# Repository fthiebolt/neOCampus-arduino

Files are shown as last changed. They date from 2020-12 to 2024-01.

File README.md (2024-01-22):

# neOCampus-arduino | home of the neOSensor end-devices #
________________________________________________________________
# WE MOVED #
# to https://gitlab.irit.fr/gis-neocampus/neosensor/neOCampus-arduino #
________________________________________________________________

This repository provides support for the following neOCampus boards:
  * neOSensor boards based on ESP32
  * neOSensor-AirQuality board (ESP32) from CNRS' LCC lab.
  * neOSensor boards based on ESP8266 (rev. >= V2)

All this work was undertaken at Université Toulouse 3 / IRIT laboratory in the context of the [neOCampus](https://neocampus.org "neOCampus corporate") operation.

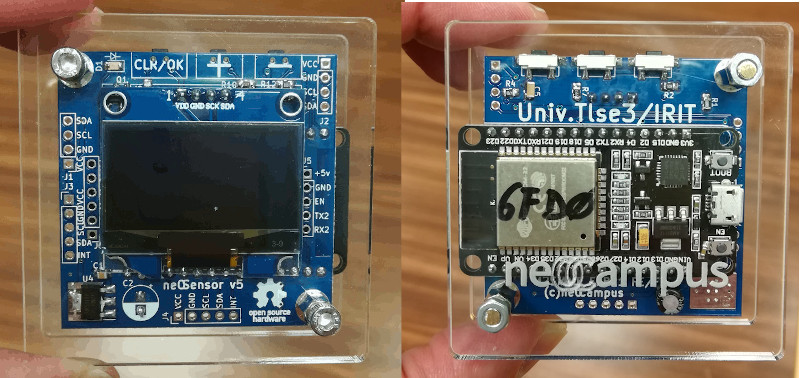
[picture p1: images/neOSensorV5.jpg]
neOSensorv5


## neOSensor boards ##
neOSensor first boards releases were based on esp8266. Nowadays, we added support for esp32 and CubeCell devices :)

We added support to our neOCampus IoT management infrastructure named [sensOCampus](https://neocampus.univ-tlse3.fr "neOCampus's Wiki Home") to enable a central configuration for all of our neOSensor boards; these boards will then be able to publish their data to our infrastructure and to have those data stored in our databases.

### neOSensor-AirQuality board ###
This board comes from CNRS LCC lab, it's a PhD work undertaken by Aymen Sendi (aymen.sendi@laas.fr).
The board features four specific sensors able to measure NO2, CO, CH20, NO2 alternate.

## Getting started ##
First of all, you ought to install esp32, esp8266 or CubeCell support in your Arduino IDE (IDE version <2).

| Device | Release | Arduino Board Manager json file |
|---|---|---|
| esp8266  | 3.1.2 | https://arduino.esp8266.com/stable/package_esp8266com_index.json |
| esp32 | 2.0.11 | https://raw.githubusercontent.com/espressif/arduino-esp32/gh-pages/package_esp32_index.json |
| CubeCell | *latest*  | https://github.com/HelTecAutomation/CubeCell-Arduino/releases/download/V1.3.0/package_CubeCell_index.json  |
| stm32 | *latest*  | https://github.com/stm32duino/BoardManagerFiles/raw/main/package_stmicroelectronics_index.json |

Then, run script `./deploy.sh` and boards will get added to your Arduino boards list :)

If not already installed, you'll need python-serial package; thus either you install it at the system level
```
[fedora] dnf -y install python3-pyserial
[ubuntu] apt-get -y install python3-serial python-is-python3
```

Once you've launched the Arduino IDE, before compiling and uploading sketches to your board, you need to undertake the following steps:
  - @preferences --> set your Arduino sketchbook to `~/neOCampus-arduino/neosensor' ... this will lead to proper libraries
  - either select boards 'ESP32 arduino' --> 'neOSensor' or 'neOSensor-AirQuality' or select board 'ESP8266 arduino' --> 'neOSensor'
  - compile and upload :)
  - debug serial link speed 115200

### WiFi setup ###
Only for ESP based boards.

Once started, the board will provides a WiFi Access Point (AP) named: `neOSensor_xxxx` where xxxx are the MAC address last bytes.

**First time setup**\
In this case, AP will get available for 5mn for you to configure SSID along with WPA2 key.
So you'll have to search with your smartphone for this peucliar AP, and then connect. In case automatic redirection does not work, open a browser with http:192.168.4.1

**Changing WiFi setup**\
Once WiFi has been set, on each reboot, the neOSensor AP will get available for 50s in order for you to tweak some parameters ... or to change the WiFi it connects to.

**Reset whole configuration**\
To erase all of the previously set parameters (including WiFi settings), press the RST button for 10s when powering the device.

***

## Create branch | development of a new feature ##
In order to work on a new feature, best is to create a new branch that will get merged later during a *pull request*

```
git switch -C feature-xxxxx
```

For first commit:
```
git push --set-upstream origin feature-xxxxx
```

... then `./git-push.sh` on subsequent commits

## Merge branch | integration of an existing feature ##
After having successfully completed yout feature, you need to create a *pull request* to get your code integrated into the main branch:

```
git branch
git checkout master
git merge feature-xxxxx
./git-push.sh
```
https://www.w3schools.com/git/git_branch_merge.asp?remote=github

In the end, you can delete your local branch: `git branch -d feature-xxxxx`

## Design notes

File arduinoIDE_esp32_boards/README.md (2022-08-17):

===== [aug.22] extending lwip with NTP servers from DHCP answer ======

WARNING: only esp32 target will benefits from this enhancement (we don't have compiled for
others targets like esp32s2, s3, c3 ...)

cp opt.h ~/.arduino15/packages/esp32/hardware/esp32/2.0.4/tools/sdk/esp32/include/lwip/lwip/src/include/lwip/
cp *.a ~/.arduino15/packages/esp32/hardware/esp32/2.0.4/tools/sdk/esp32/lib/

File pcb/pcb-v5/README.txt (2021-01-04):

This directory holds the following:

- pcbv5.pro         --> main neOSensor board (esp32 30 pins based version)
    [dec.20] pre-release in lora repository @ bitbucket
- panelization files (4 designs in a single 100x100mm board)

To launch Kicad: #> kicad xxx.pro

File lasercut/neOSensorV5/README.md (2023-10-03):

# neOSensor V5 | PMMA enclosure #
_________________________________

** .wcvr files ** are from the CampusFab's laser cutter

DXF files have been edited through the 'LibreCAD' tool

## FILES ##
  - 

TO BE CONTINUED
 24K -rw-r--r-- 1 francois cloud  24K Oct  7  2021 first-run.plt
984K -rw-r--r-- 1 francois cloud 983K Dec 13  2021 first-run.wcvr
1,6M -rw-r--r-- 1 francois cloud 1,6M Dec 13  2021 large-plate.wcvr
 28K -rw-r--r-- 1 francois cloud  28K Dec 13  2021 neOSensor-sds011_flat.dxf
120K -rw-r--r-- 1 francois cloud 118K Dec 13  2021 neOSensor-sds011_flat.wcvr
 20K -rw-r--r-- 1 francois cloud  19K Jun 18  2021 neOSensor_IR.dxf
 20K -rw-r--r-- 1 francois cloud  20K Sep 28  2021 neOSensor_V2.1_back.dxf
 20K -rw-r--r-- 1 francois cloud  19K Sep 28  2021 neOSensor_V2.2_back.dxf
 48K -rw-r--r-- 1 francois cloud  45K Dec  9  2021 neOSensor_bureau.dxf
 32K -rw-r--r-- 1 francois cloud  32K Dec  7  2021 neOSensor_bureauV2_Bottom5mm.dxf
 40K -rw-r--r-- 1 francois cloud  38K Dec  7  2021 neOSensor_bureauV2_Top3mm.dxf
100K -rw-r--r-- 1 francois cloud  98K Dec 13  2021 neOSensor_bureau-run1.wcvr
 88K -rw-r--r-- 1 francois cloud  87K Apr  9  2021 neOSensor_logo.dxf
 20K -rw-r--r-- 1 francois cloud  18K Apr  9  2021 neOSensor_plain.dxf
1,5M -rw-r--r-- 1 francois cloud 1,5M Dec 13  2021 second-run.wcvr

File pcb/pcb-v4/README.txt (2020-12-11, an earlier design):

This directory holds several Kicad5 pcbs:

- pcbv4.pro         --> main neOSensor board (esp8266 version)
- pcbv4-temp.pro    --> addon board featuring a temperature sensor
- neOSensorV4_panel --> neOSensors panelized ;)

Note: we get inspiration from Arduino MKR1300 schematic for power supply

To launch Kicad: #> kicad xxx.pro

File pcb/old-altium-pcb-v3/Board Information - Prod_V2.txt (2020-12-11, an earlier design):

Board Information Report
Filename     : H:\Mes documents\DEV\ALTIUM\Altium conceptions\Son_BU\Prod_V2.PcbDoc
Date         : 04/04/2017
Time         : 14:27:02
Time Elapsed : 00:00:00

General
    Board Size, 152.4mmx101.6mm
    Components on board, 0
count : 2

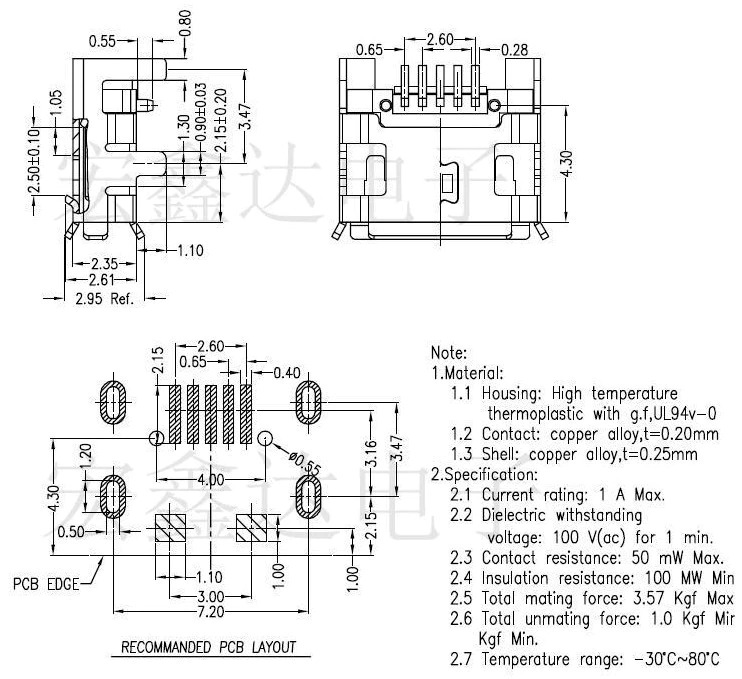
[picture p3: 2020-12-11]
pcb/doc/micro-usb-aliexpress-detail2.jpg

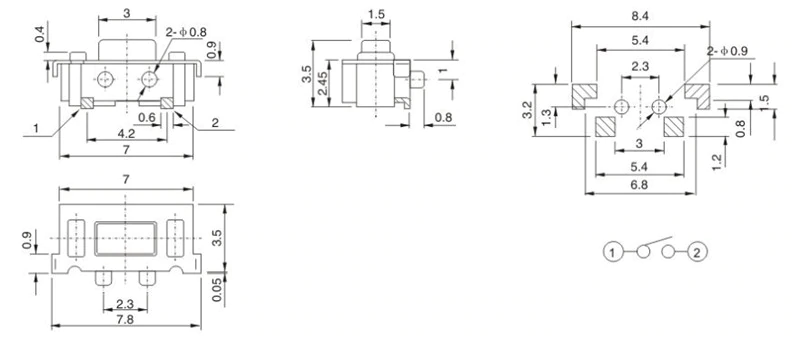
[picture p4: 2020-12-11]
pcb/doc/G71Y_horizontal_button.png

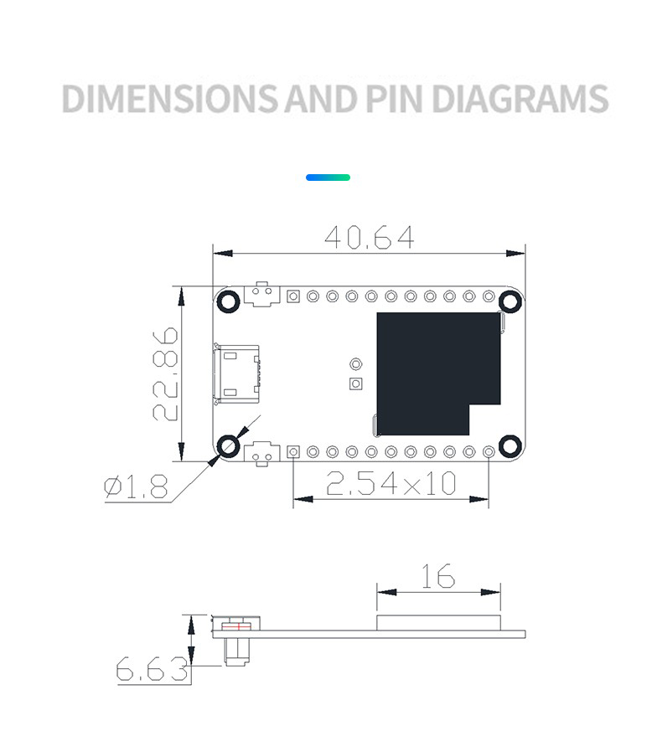
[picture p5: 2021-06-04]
pcb/doc/HTCC-AB01-mechnical.jpg

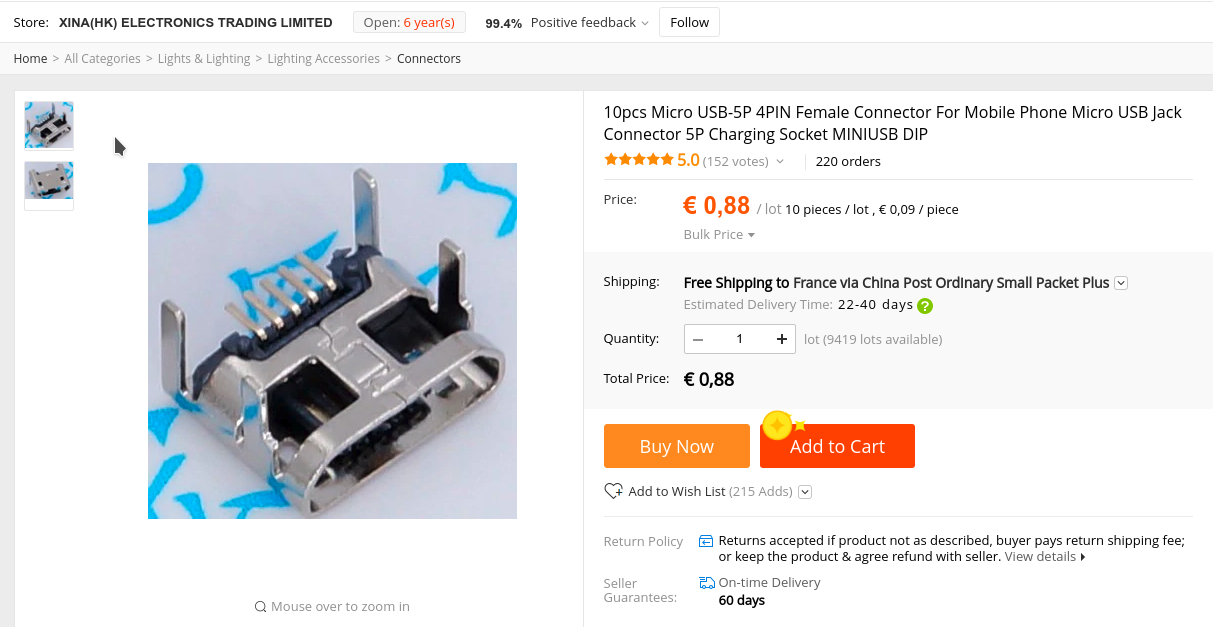
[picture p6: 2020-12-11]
pcb/doc/micro-usb-aliexpress.png

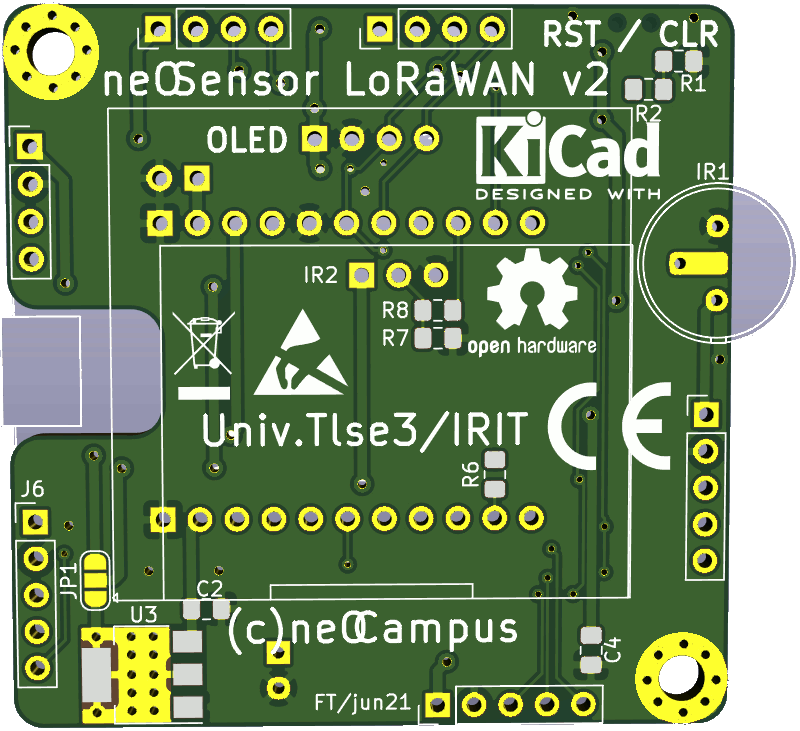
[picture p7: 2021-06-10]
pcb/lorawan-v2/neOsensor-LoRaWANV2.png

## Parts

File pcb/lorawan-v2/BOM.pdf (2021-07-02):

neOsensor-LoRaWANV2

Page 1

Reference(s) | Value | LibPart | Footprint
C1 | 1uF | Device:C_Small | Capacitor_SMD:C_0805_2012Metric_Pad1.15x1.40mm_HandSolder
C2 | 100n | Device:C_Small | Capacitor_SMD:C_0805_2012Metric_Pad1.15x1.40mm_HandSolder
C3 | 100ÂµF 6.3v | Device:CP1_Small | Capacitor_THT:CP_Radial_D5.0mm_P2.50mm
C4 | 100n | Device:C_Small | Capacitor_SMD:C_0805_2012Metric_Pad1.18x1.45mm_HandSolder
H1, H2 | 3.2mm for MH3 screw | Mechanical:MountingHole_Pad | MountingHole:MountingHole_3.2mm_M3_Pad
IR1 | IRsensor | neosensor_addon:IRsensor | neosensor_addon:IRsensor_TH_and_smd
IR2 | HC-SR01 | neosensor_addon:HC-SR01 | neosensor_addon:PIR_HC-SR01
J1, J3, J5, J6, J7 | Conn_01x05 | Connector_Generic:Conn_01x05 | Connector_PinHeader_2.54mm:PinHeader_1x05_P2.54mm_Vertical
J2 | Conn_01x02 | Connector_Generic:Conn_01x02 | Connector_JST:JST_PH_S2B-PH-K_1x02_P2.00mm_Horizontal
J4 | Conn_01x04 | Connector_Generic:Conn_01x04 | Connector_PinHeader_2.54mm:PinHeader_1x04_P2.54mm_Vertical
JP1 | SolderJumper_3_Open | Jumper:SolderJumper_3_Open | Jumper:SolderJumper-3_P1.3mm_Open_RoundedPad1.0x1.5mm
R1, R2, R6 | 15k | Device:R_Small | Resistor_SMD:R_0805_2012Metric_Pad1.15x1.40mm_HandSolder
R3, R4 | 4K7 | Device:R_Small | Resistor_SMD:R_0805_2012Metric_Pad1.15x1.40mm_HandSolder
R5, R8 | 470 Device:R_Small | | Resistor_SMD:R_0805_2012Metric_Pad1.15x1.40mm_HandSolder
R7 | 47K | Device:R_Small | Resistor_SMD:R_0805_2012Metric_Pad1.15x1.40mm_HandSolder
SW1 | G71Y | neosensor_addon:G71Y | neosensor_addon:G71Y_Âµsw_smd
U1 | OLED1.3_I2C | neosensor_addon:OLED1.3_I2C | neosensor_addon:OLED1.3_I2C
U2 | ATECC508A | neosensor_addon:ATECC508A | neosensor_addon:SOIC-8_3.9x5.4mm_P1.27mm_HandSolder
U3 | AMS1117-3.3 | Regulator_Linear:AMS1117-3.3 | Package_TO_SOT_SMD:SOT-223-3_TabPin2
U4 | HTCC-AB01 | neosensor_addon:HTCC-AB01 | neosensor_addon:HTCC-AB01

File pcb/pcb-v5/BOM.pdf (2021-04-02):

neOSensorV5.1

Page 1

Reference(s) | Value | LibPart | Footprint
C1, C3 | 100nF | Device:C_Small | Resistor_SMD:R_0805_2012Metric_Pad1.20x1.40mm_HandSolder
C2 | 100µF 6.3v | Device:CP1_Small | Capacitor_THT:CP_Radial_D5.0mm_P2.50mm
C4, C5 | 1uF | Device:C_Small | Resistor_SMD:R_0805_2012Metric_Pad1.20x1.40mm_HandSolder
D1 | Red | Device:LED_Small_ALT | LED_SMD:LED_0805_2012Metric_Pad1.15x1.40mm_HandSolder
H1, H2 | 3.2mm for MH3 screw | Mechanical:MountingHole_Pad | MountingHole:MountingHole_3.2mm_M3_Pad
J1, J2 | Conn_01x04 | Connector_Generic:Conn_01x04 | Connector_PinHeader_2.54mm:PinHeader_1x04_P2.54mm_Vertical
J3, J4, J5 | Conn_01x05 | Connector_Generic:Conn_01x05 | Connector_PinHeader_2.54mm:PinHeader_1x05_P2.54mm_Vertical
J6 | Conn_01x06 | Connector_Generic:Conn_01x06 | Connector_PinHeader_2.54mm:PinHeader_1x06_P2.54mm_Vertical
Q1 | 2N7002 | Transistor_FET:2N7002 | Package_TO_SOT_SMD:SOT-23_Handsoldering
R1 | 150 Device:R_Small | | Resistor_SMD:R_0805_2012Metric_Pad1.20x1.40mm_HandSolder
R2, R7, R9, R10, R11, R12, R21 | 15k | Device:R_Small | Resistor_SMD:R_0805_2012Metric_Pad1.20x1.40mm_HandSolder
R3, R5 | 470 Device:R_Small | | Resistor_SMD:R_0805_2012Metric_Pad1.20x1.40mm_HandSolder
R4, R8 | 4K7 | Device:R_Small | Resistor_SMD:R_0805_2012Metric_Pad1.20x1.40mm_HandSolder
R13, R14, R15, R18 | 22k | Device:R_Small | Resistor_SMD:R_0805_2012Metric_Pad1.20x1.40mm_HandSolder
R16, R17, R19, R20 | 33k | Device:R_Small | Resistor_SMD:R_0805_2012Metric_Pad1.20x1.40mm_HandSolder
SW1 | clear | neosensor_addon:G71Y | neosensor_addon:G71Y_µsw_smd
SW2 | + | neosensor_addon:G71Y | neosensor_addon:G71Y_µsw_smd
SW3 | - | neosensor_addon:G71Y | neosensor_addon:G71Y_µsw_smd
U1 | HC-SR01 | neosensor_addon:HC-SR01 | neosensor_addon:PIR_HC-SR01
U2 | OLED1.3_I2C | neosensor_addon:OLED1.3_I2C | neosensor_addon:OLED1.3_I2C
U3 | ESP32_dev_30p | neosensor_addon:ESP32_dev_30p | neosensor_addon:ESP32_dev_30p
U4 | AMS1117-3.3 | Regulator_Linear:AMS1117-3.3 | Package_TO_SOT_SMD:SOT-223-3_TabPin2
U5 | LM2902 | Amplifier_Operational:LM2902 | Package_SO:SO-14_5.3x10.2mm_P1.27mm

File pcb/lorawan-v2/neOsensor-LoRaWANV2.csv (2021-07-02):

Source: | /nfs/home/francois/neOCampus-arduino/pcb/lorawan-v2/neOsensor-LoRaWANV2.sch
Date: | ven. 02 juil. 2021 12:56:47 CEST
Tool: | Eeschema 5.1.8-1.fc31
Generator: | /usr/share/kicad/plugins/bom_csv_grouped_by_value.py
Component Count: | 29
Individual Components:
Item | Qty | Reference(s) | Value | LibPart | Footprint | Datasheet
 |  | C1 | 1uF | Device:C_Small | Capacitor_SMD:C_0805_2012Metric_Pad1.15x1.40mm_HandSolder | ~
 |  | C2 | 100n | Device:C_Small | Capacitor_SMD:C_0805_2012Metric_Pad1.15x1.40mm_HandSolder | ~
 |  | C3 | 100µF 6.3v | Device:CP1_Small | Capacitor_THT:CP_Radial_D5.0mm_P2.50mm | ~
 |  | C4 | 100n | Device:C_Small | Capacitor_SMD:C_0805_2012Metric_Pad1.18x1.45mm_HandSolder | ~
 |  | H1 | 3.2mm for MH3 screw | Mechanical:MountingHole_Pad | MountingHole:MountingHole_3.2mm_M3_Pad | ~
 |  | H2 | 3.2mm for MH3 screw | Mechanical:MountingHole_Pad | MountingHole:MountingHole_3.2mm_M3_Pad | ~
 |  | IR1 | IRsensor | neosensor_addon:IRsensor | neosensor_addon:IRsensor_TH_and_smd
 |  | IR2 | HC-SR01 | neosensor_addon:HC-SR01 | neosensor_addon:PIR_HC-SR01
 |  | J1 | Conn_01x05 | Connector_Generic:Conn_01x05 | Connector_PinHeader_2.54mm:PinHeader_1x05_P2.54mm_Vertical | ~
 |  | J2 | Conn_01x02 | Connector_Generic:Conn_01x02 | Connector_JST:JST_PH_S2B-PH-K_1x02_P2.00mm_Horizontal | ~
 |  | J3 | Conn_01x05 | Connector_Generic:Conn_01x05 | Connector_PinHeader_2.54mm:PinHeader_1x05_P2.54mm_Vertical | ~
 |  | J4 | Conn_01x04 | Connector_Generic:Conn_01x04 | Connector_PinHeader_2.54mm:PinHeader_1x04_P2.54mm_Vertical | ~
 |  | J5 | Conn_01x05 | Connector_Generic:Conn_01x05 | Connector_PinHeader_2.54mm:PinHeader_1x05_P2.54mm_Vertical | ~
 |  | J6 | Conn_01x05 | Connector_Generic:Conn_01x05 | Connector_PinHeader_2.54mm:PinHeader_1x05_P2.54mm_Vertical | ~
 |  | J7 | Conn_01x05 | Connector_Generic:Conn_01x05 | Connector_PinHeader_2.54mm:PinHeader_1x05_P2.54mm_Vertical | ~
 |  | JP1 | SolderJumper_3_Open | Jumper:SolderJumper_3_Open | Jumper:SolderJumper-3_P1.3mm_Open_RoundedPad1.0x1.5mm | ~
 |  | R1 | 15k | Device:R_Small | Resistor_SMD:R_0805_2012Metric_Pad1.15x1.40mm_HandSolder | ~
 |  | R2 | 15k | Device:R_Small | Resistor_SMD:R_0805_2012Metric_Pad1.15x1.40mm_HandSolder | ~
 |  | R3 | 4K7 | Device:R_Small | Resistor_SMD:R_0805_2012Metric_Pad1.15x1.40mm_HandSolder | ~
 |  | R4 | 4K7 | Device:R_Small | Resistor_SMD:R_0805_2012Metric_Pad1.15x1.40mm_HandSolder | ~
 |  | R5 | 470 | Device:R_Small | Resistor_SMD:R_0805_2012Metric_Pad1.15x1.40mm_HandSolder | ~
 |  | R6 | 15k | Device:R_Small | Resistor_SMD:R_0805_2012Metric_Pad1.15x1.40mm_HandSolder | ~
 |  | R7 | 47K | Device:R_Small | Resistor_SMD:R_0805_2012Metric_Pad1.15x1.40mm_HandSolder | ~
 |  | R8 | 470 | Device:R_Small | Resistor_SMD:R_0805_2012Metric_Pad1.15x1.40mm_HandSolder | ~
 |  | SW1 | G71Y | neosensor_addon:G71Y | neosensor_addon:G71Y_µsw_smd
 |  | U1 | OLED1.3_I2C | neosensor_addon:OLED1.3_I2C | neosensor_addon:OLED1.3_I2C | https://cdn-shop.adafruit.com/datasheets/SSD1306.pdf
 |  | U2 | ATECC508A | neosensor_addon:ATECC508A | neosensor_addon:SOIC-8_3.9x5.4mm_P1.27mm_HandSolder
 |  | U3 | AMS1117-3.3 | Regulator_Linear:AMS1117-3.3 | Package_TO_SOT_SMD:SOT-223-3_TabPin2 | http://www.advanced-monolithic.com/pdf/ds1117.pdf
 |  | U4 | HTCC-AB01 | neosensor_addon:HTCC-AB01 | neosensor_addon:HTCC-AB01
Collated Components:
Item | Qty | Reference(s) | Value | LibPart | Footprint | Datasheet
1 | 1 | C1 | 1uF | Device:C_Small | Capacitor_SMD:C_0805_2012Metric_Pad1.15x1.40mm_HandSolder | ~
2 | 1 | C2 | 100n | Device:C_Small | Capacitor_SMD:C_0805_2012Metric_Pad1.15x1.40mm_HandSolder | ~
3 | 1 | C3 | 100µF 6.3v | Device:CP1_Small | Capacitor_THT:CP_Radial_D5.0mm_P2.50mm | ~
4 | 1 | C4 | 100n | Device:C_Small | Capacitor_SMD:C_0805_2012Metric_Pad1.18x1.45mm_HandSolder | ~
5 | 2 | H1, H2 | 3.2mm for MH3 screw | Mechanical:MountingHole_Pad | MountingHole:MountingHole_3.2mm_M3_Pad | ~
6 | 1 | IR1 | IRsensor | neosensor_addon:IRsensor | neosensor_addon:IRsensor_TH_and_smd
7 | 1 | IR2 | HC-SR01 | neosensor_addon:HC-SR01 | neosensor_addon:PIR_HC-SR01
8 | 5 | J1, J3, J5, J6, J7 | Conn_01x05 | Connector_Generic:Conn_01x05 | Connector_PinHeader_2.54mm:PinHeader_1x05_P2.54mm_Vertical | ~
9 | 1 | J2 | Conn_01x02 | Connector_Generic:Conn_01x02 | Connector_JST:JST_PH_S2B-PH-K_1x02_P2.00mm_Horizontal | ~
10 | 1 | J4 | Conn_01x04 | Connector_Generic:Conn_01x04 | Connector_PinHeader_2.54mm:PinHeader_1x04_P2.54mm_Vertical | ~
11 | 1 | JP1 | SolderJumper_3_Open | Jumper:SolderJumper_3_Open | Jumper:SolderJumper-3_P1.3mm_Open_RoundedPad1.0x1.5mm | ~
12 | 3 | R1, R2, R6 | 15k | Device:R_Small | Resistor_SMD:R_0805_2012Metric_Pad1.15x1.40mm_HandSolder | ~
13 | 2 | R3, R4 | 4K7 | Device:R_Small | Resistor_SMD:R_0805_2012Metric_Pad1.15x1.40mm_HandSolder | ~
14 | 2 | R5, R8 | 470 | Device:R_Small | Resistor_SMD:R_0805_2012Metric_Pad1.15x1.40mm_HandSolder | ~
15 | 1 | R7 | 47K | Device:R_Small | Resistor_SMD:R_0805_2012Metric_Pad1.15x1.40mm_HandSolder | ~
16 | 1 | SW1 | G71Y | neosensor_addon:G71Y | neosensor_addon:G71Y_µsw_smd
17 | 1 | U1 | OLED1.3_I2C | neosensor_addon:OLED1.3_I2C | neosensor_addon:OLED1.3_I2C | https://cdn-shop.adafruit.com/datasheets/SSD1306.pdf
18 | 1 | U2 | ATECC508A | neosensor_addon:ATECC508A | neosensor_addon:SOIC-8_3.9x5.4mm_P1.27mm_HandSolder
19 | 1 | U3 | AMS1117-3.3 | Regulator_Linear:AMS1117-3.3 | Package_TO_SOT_SMD:SOT-223-3_TabPin2 | http://www.advanced-monolithic.com/pdf/ds1117.pdf
20 | 1 | U4 | HTCC-AB01 | neosensor_addon:HTCC-AB01 | neosensor_addon:HTCC-AB01

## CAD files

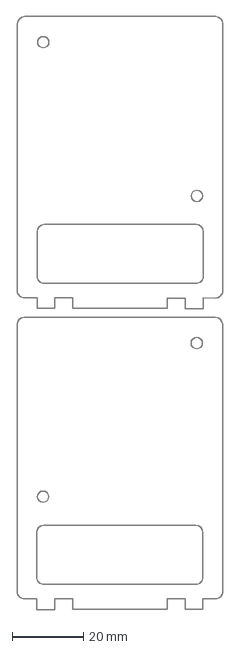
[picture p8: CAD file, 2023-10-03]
lasercut/neOSensorV5/neOSensor_bureauV2_Top3mm.dxf
57.5 x 166.2 mm

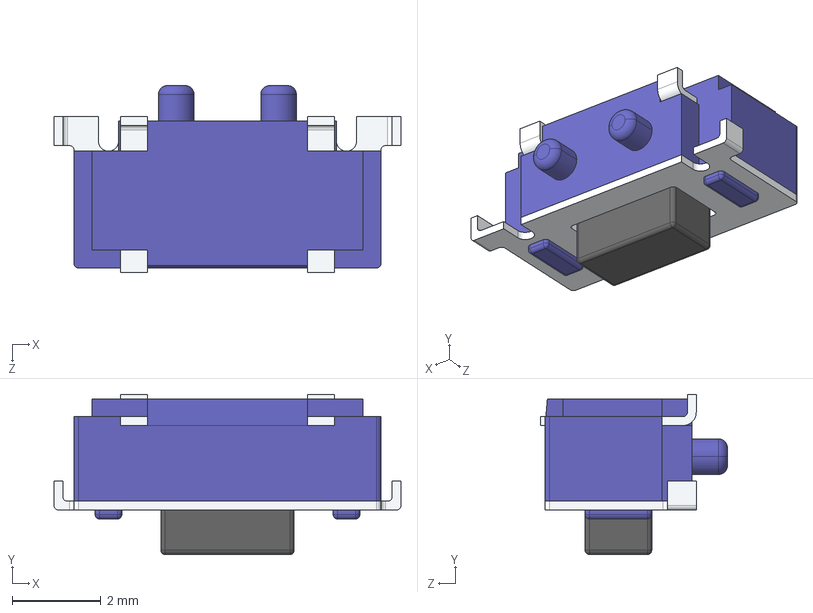
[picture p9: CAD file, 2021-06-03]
pcb/kicad-libs/3d/g71y.STEP
7.80 x 3.60 x 4.20 mm
User Library-it-1188e_SW3dPS-E-Switch_-_TL3330AF130QG_(Tact_Switch,_SMD)
User Library-it-1188e_SW3dPS-E-Switch_-_TL3330AF130QG_(Tact_Switch,_SMD)001
User Library-it-1188e_SW3dPS-E-Switch_-_TL3330AF130QG_(Tact_Switch,_SMD)002
User Library-it-1188e_SW3dPS-E-Switch_-_TL3330AF130QG_(Tact_Switch,_SMD)003
User Library-it-1188e_SW3dPS-E-Switch_-_TL3330AF130QG_(Tact_Switch,_SMD)004
User Library-it-1188e_Fillet
User Library-it-1188e_Fillet001

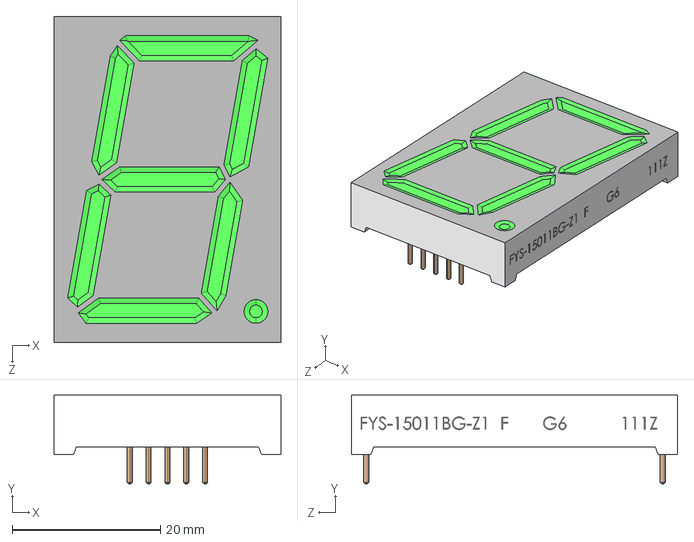
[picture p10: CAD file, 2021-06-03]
pcb/kicad-libs/3d/7segments.STEP
30.6 x 12.0 x 44.0 mm

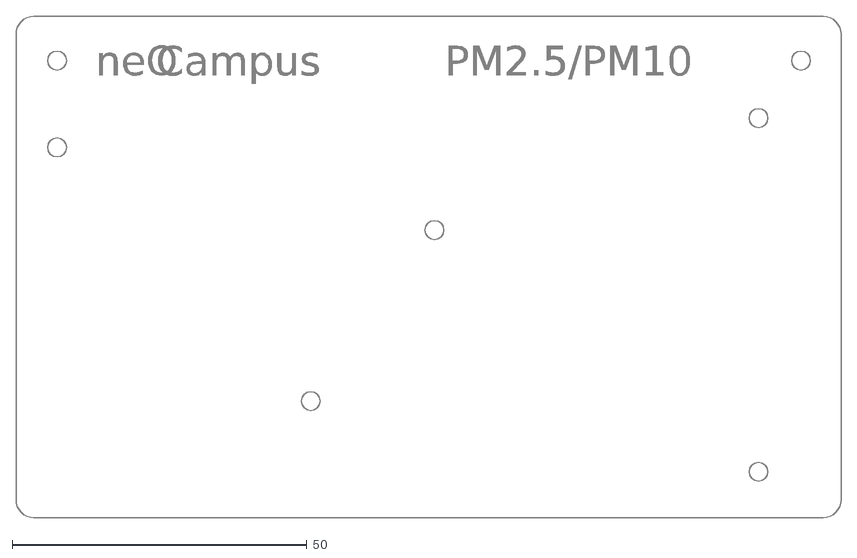
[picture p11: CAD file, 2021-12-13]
lasercut/neOSensorV5/neOSensor-sds011_flat.dxf
neO
Campus
PM2.5/PM10

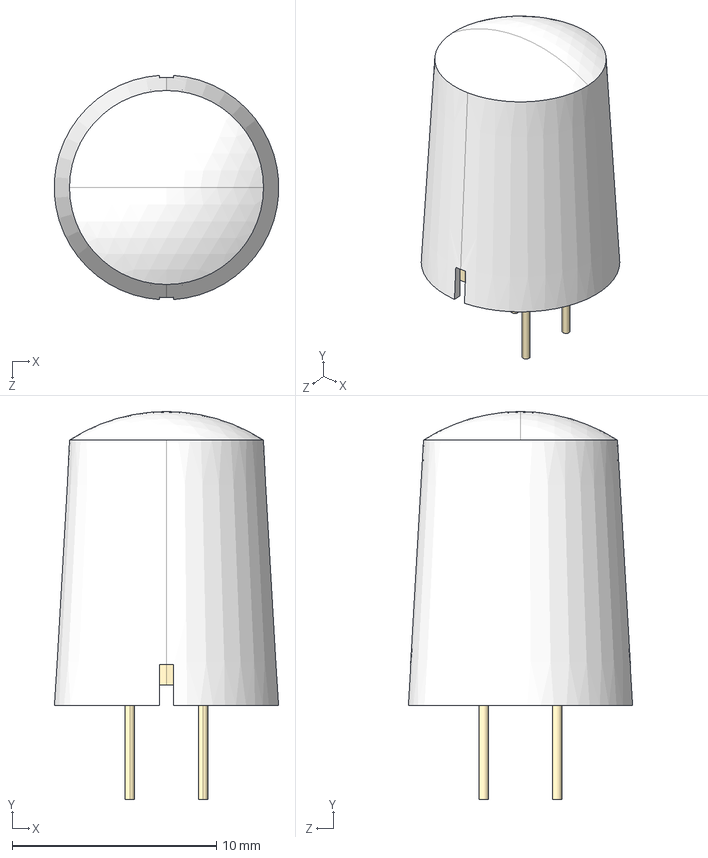
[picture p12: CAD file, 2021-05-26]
pcb/kicad-libs/3d/IRsensor_TH_and_smd.STEP
11.0 x 19.0 x 11.0 mm

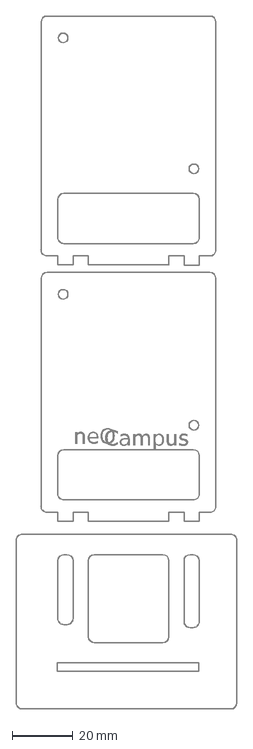
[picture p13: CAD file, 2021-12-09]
lasercut/neOSensorV5/neOSensor_bureau.dxf
neO
Campus

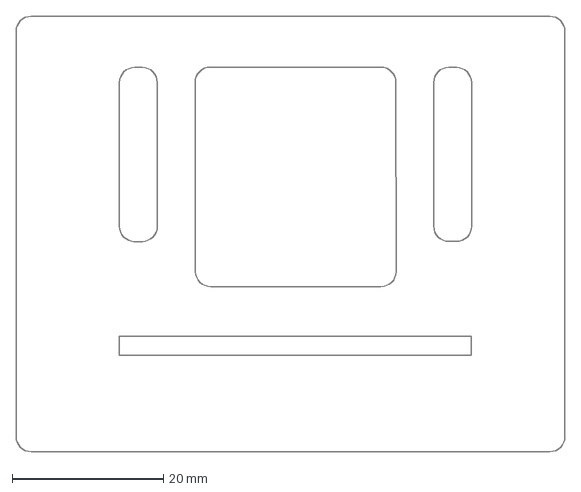
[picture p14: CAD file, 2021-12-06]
lasercut/neOSensorV5/neOSensor_bureauV2_Bottom5mm.dxf
72.5 x 57.5 mm

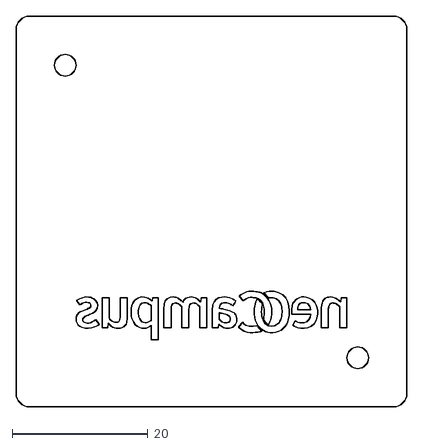
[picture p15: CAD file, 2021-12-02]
lasercut/neOSensorV5/neOSensor_logo.dxf
57.5 x 57.5

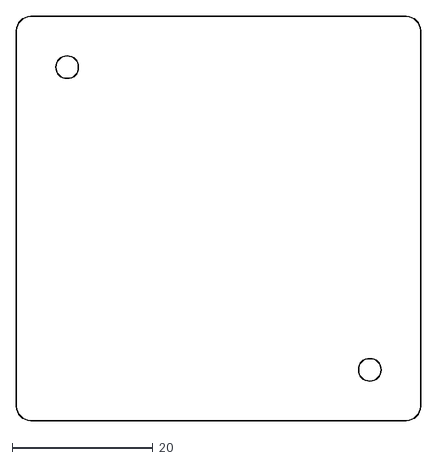
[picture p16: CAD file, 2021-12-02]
lasercut/neOSensorV5/neOSensor_plain.dxf
57.5 x 57.5

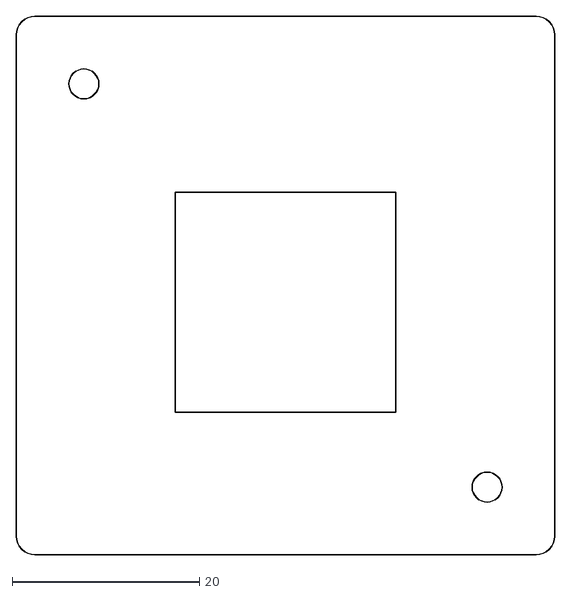
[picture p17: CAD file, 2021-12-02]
lasercut/neOSensorV5/neOSensor_IR.dxf
57.5 x 57.5

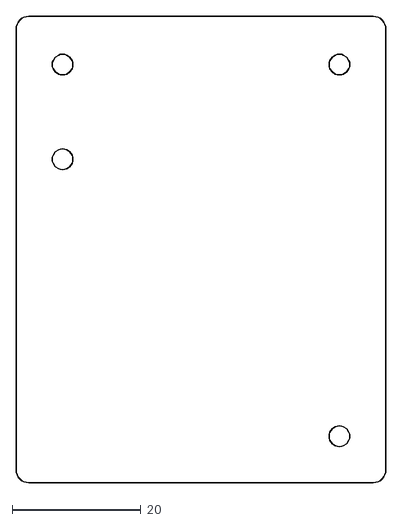
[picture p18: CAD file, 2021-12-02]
lasercut/neOSensorV5/neOSensor_V2.2_back.dxf
57.5 x 72.5

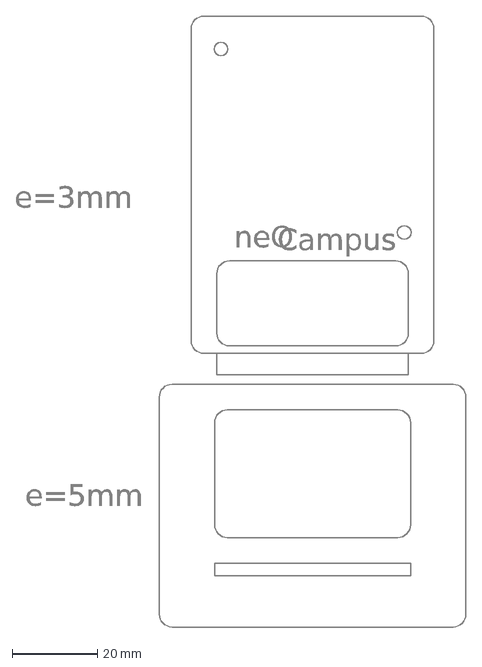
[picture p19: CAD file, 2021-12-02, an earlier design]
lasercut/neOSensorV5/neOSensor_bureauV2.dxf
neO
Campus
e=3mm
e=5mm

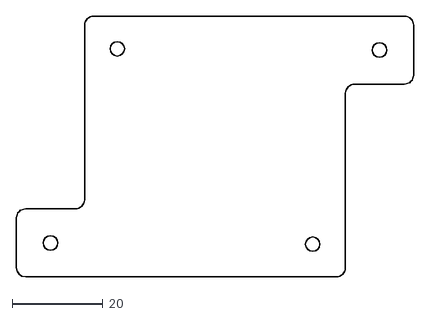
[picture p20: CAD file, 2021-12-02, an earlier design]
lasercut/neOSensorV5/neOSensor_V2.1_back.dxf
87.5 x 57.5

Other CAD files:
lasercut/neOSensorV5/tmp_neOSensor_bureauV2_Top3mm.dxf
lasercut/neOSensorV5/#neOSensor_bureauV2_Top3mm.dxf

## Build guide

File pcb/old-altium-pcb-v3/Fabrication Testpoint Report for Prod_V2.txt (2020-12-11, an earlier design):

Net         Name        X Coord     Y Coord     Side        Hole Size   Type

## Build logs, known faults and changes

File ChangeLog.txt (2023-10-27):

#
# neOCampus operation
# Note: 'UNPUBLISHED' means the release may have been installed on some
#	devices BUT not set as globally available for firmware upgrades
# (c) neOCampus / F.Thiebolt Université Toulouse3, Laboratoire IRIT

=== Release 231027 for esp32 only (Arduino Core ESP32 2.0.11)
Added support to save WiFi credentials retrieved from JSON file to get automatically
  saved in NVS WiFi credentials area if this later does not already exists

=== [jul.23] SDK upgrade ===
Updated to latest esp32 core Arduino (i.e 2.0.11)

=== Release 230528 / feature-NVSsensocampus
Bumps to esp32 2.0.9
Bumps to esp8266 3.1.2
- switch WiFi to both 802.11b AND 802.11g (DSI cut down 802.11b !!)
- esp8266 now features a configTzTime() that unifies NTP setup for both ESPs
- NVS WiFinamespace to save WiFi credentials (in order to avoid SPIFFS
	partitionning issues)
- NVS SENSOnamespace to sensOCampus credentials (MQTT creds)
- recompiled lwip for NTP server support from DHCP answer (IDF 4.4.4)

=== Release 221225 / backport-NVSnamespace
Note: temporary release only intended to neOSensors with FW <= 220815
Based on Release 220815 / esp32 2.0.4 (because later releases broke the SPIFFS partitioning)
- backport NVS namespace for WiFi credentials

=== [UNPUBLISHED] Release 230116 / feature-SDKupgrade
Bumps to esp32 2.0.6
Bumps to esp8266 3.1.0
- force 802.11b for both ESP8266 and ESP32 --> solved our DHCP issues :D
- WARNING: breaks SPIFFS format@ESP32 ==> reformat @ reboot ==> per device setup :'(
	(hopefully) no SPIFFS format change @ ESP8266
- WiFiManager 2.0.15-rc1 no debug --> revert to 2.0.14-beta
- newer WiFiManager introduces ASYNC SCAN ==> very slow (almost unanswered)
[esp32]
- recompiled lwip for NTP server support from DHCP answer (IDF 4.4.3)

=== Release 220815 / feature-SDKupgrade
Bumps to esp32 2.0.4
Bumps to esp8266 3.0.2
- we're still using the deprecated SPIFFS filesystem
- updated boards.local.txt
- _http_get now makes use of newer API involving a WIFIClient variable
- uniformized sntp includes for all ESP :)
- WIFImanager now used without mod
- switched noise ISR from ICACHE_RAM_ATTR to newer IRAM_ATTR
- improved NTP sync IPaddr used
[esp32]
- recompiled lwip for NTP server support from DHCP answer (IDF 4.4.2)
[esp8266]
- analogWrite now makes use of analogWriteRange set to 1023 to match previous
defaults
- setting up defaults partitionning IRAM to 32kb (defaults) in
boards.local.txt

=== Release 220328
- save WiFi credentials even if wrongly typed or end device has not been able
to connect to WiFi gateway

===
=== Changes prior to 2022
 * F.Thiebolt   nov.21  corrected timezone definition for esp32
 *						added support for various serial sensors like PMSx003, SDS011 and IKEA Vindriktning :D
 *						added support for digital inputs (PIR & switches)
 *						introduced the cooldown approach and data integration
 *						... means that we'll only send data when they differ from the previously sent
 * F.Thiebolt   sep.21  added display module support (e.g oled or 7segment displays)
 * F.Thiebolt   aug.21  started digital inputs support (e.g PIR sensor)
 *                      added support for shared JSON document for data exchange
 *                      between modules
 * F.Thiebolt	apr.21	added support for 3 NTP servers + NTP from DHCP to lwip
 *						Have a look to `arduinoIDE_esp32_boards/README.md`
 * F.Thiebolt   aug.20  initial port from neOSensor based on ESP8266
 *                      added esp32 adc calibration support
 *                      setupNTP called AFTER network setup
 * 						new definition board for neOSensor-AirQuality board
 *						added definition board for (future) neOSensor esp32 based board\
 *						added suppport for boards configuration via sensOCampus JSON config\
 *						added Arduino IDE support for our various neOSensor boards

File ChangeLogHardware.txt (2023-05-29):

#
# neOCampus operation
# (c) neOCampus / F.Thiebolt Université Toulouse3, Laboratoire IRIT

=== (upcoming) HW Release neOSensorV5.2
- add 0805 cap for those ESP32 that miss it on EN pin
- test DAC detect on ESP8266 (check no interference with SCD4x autodetect)
- switch to ESP32 layout featuring unaligned pins
- 90° rotate of C2 capacitor

===
=== Changes prior to 2023
 * F.Thiebolt	jun.21	added KiCad PCB for LoRaWAN V2 (Heltec CubeCell)
 * F.Thiebolt	apr.21	added KiCad PCB for neOSensor v5.1 (ESP32 based)
 * F.Thiebolt	feb.21	added KiCad PCB for neOSensor v5 (ESP32 based)
 * F.Thiebolt	dec.20	added PCB from ESP8266 version 4 (KiCad)

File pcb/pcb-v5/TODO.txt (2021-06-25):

=== neOSensor PCB V5.2 ===
TODO list:
  * instead of OLED and IRsensor labels, you may add VCC/GND/SCL/SDA labels on silk screen
  * add 470 ohm in line with IR pin @ esp32
  * add ATECC508A crypt eeprom

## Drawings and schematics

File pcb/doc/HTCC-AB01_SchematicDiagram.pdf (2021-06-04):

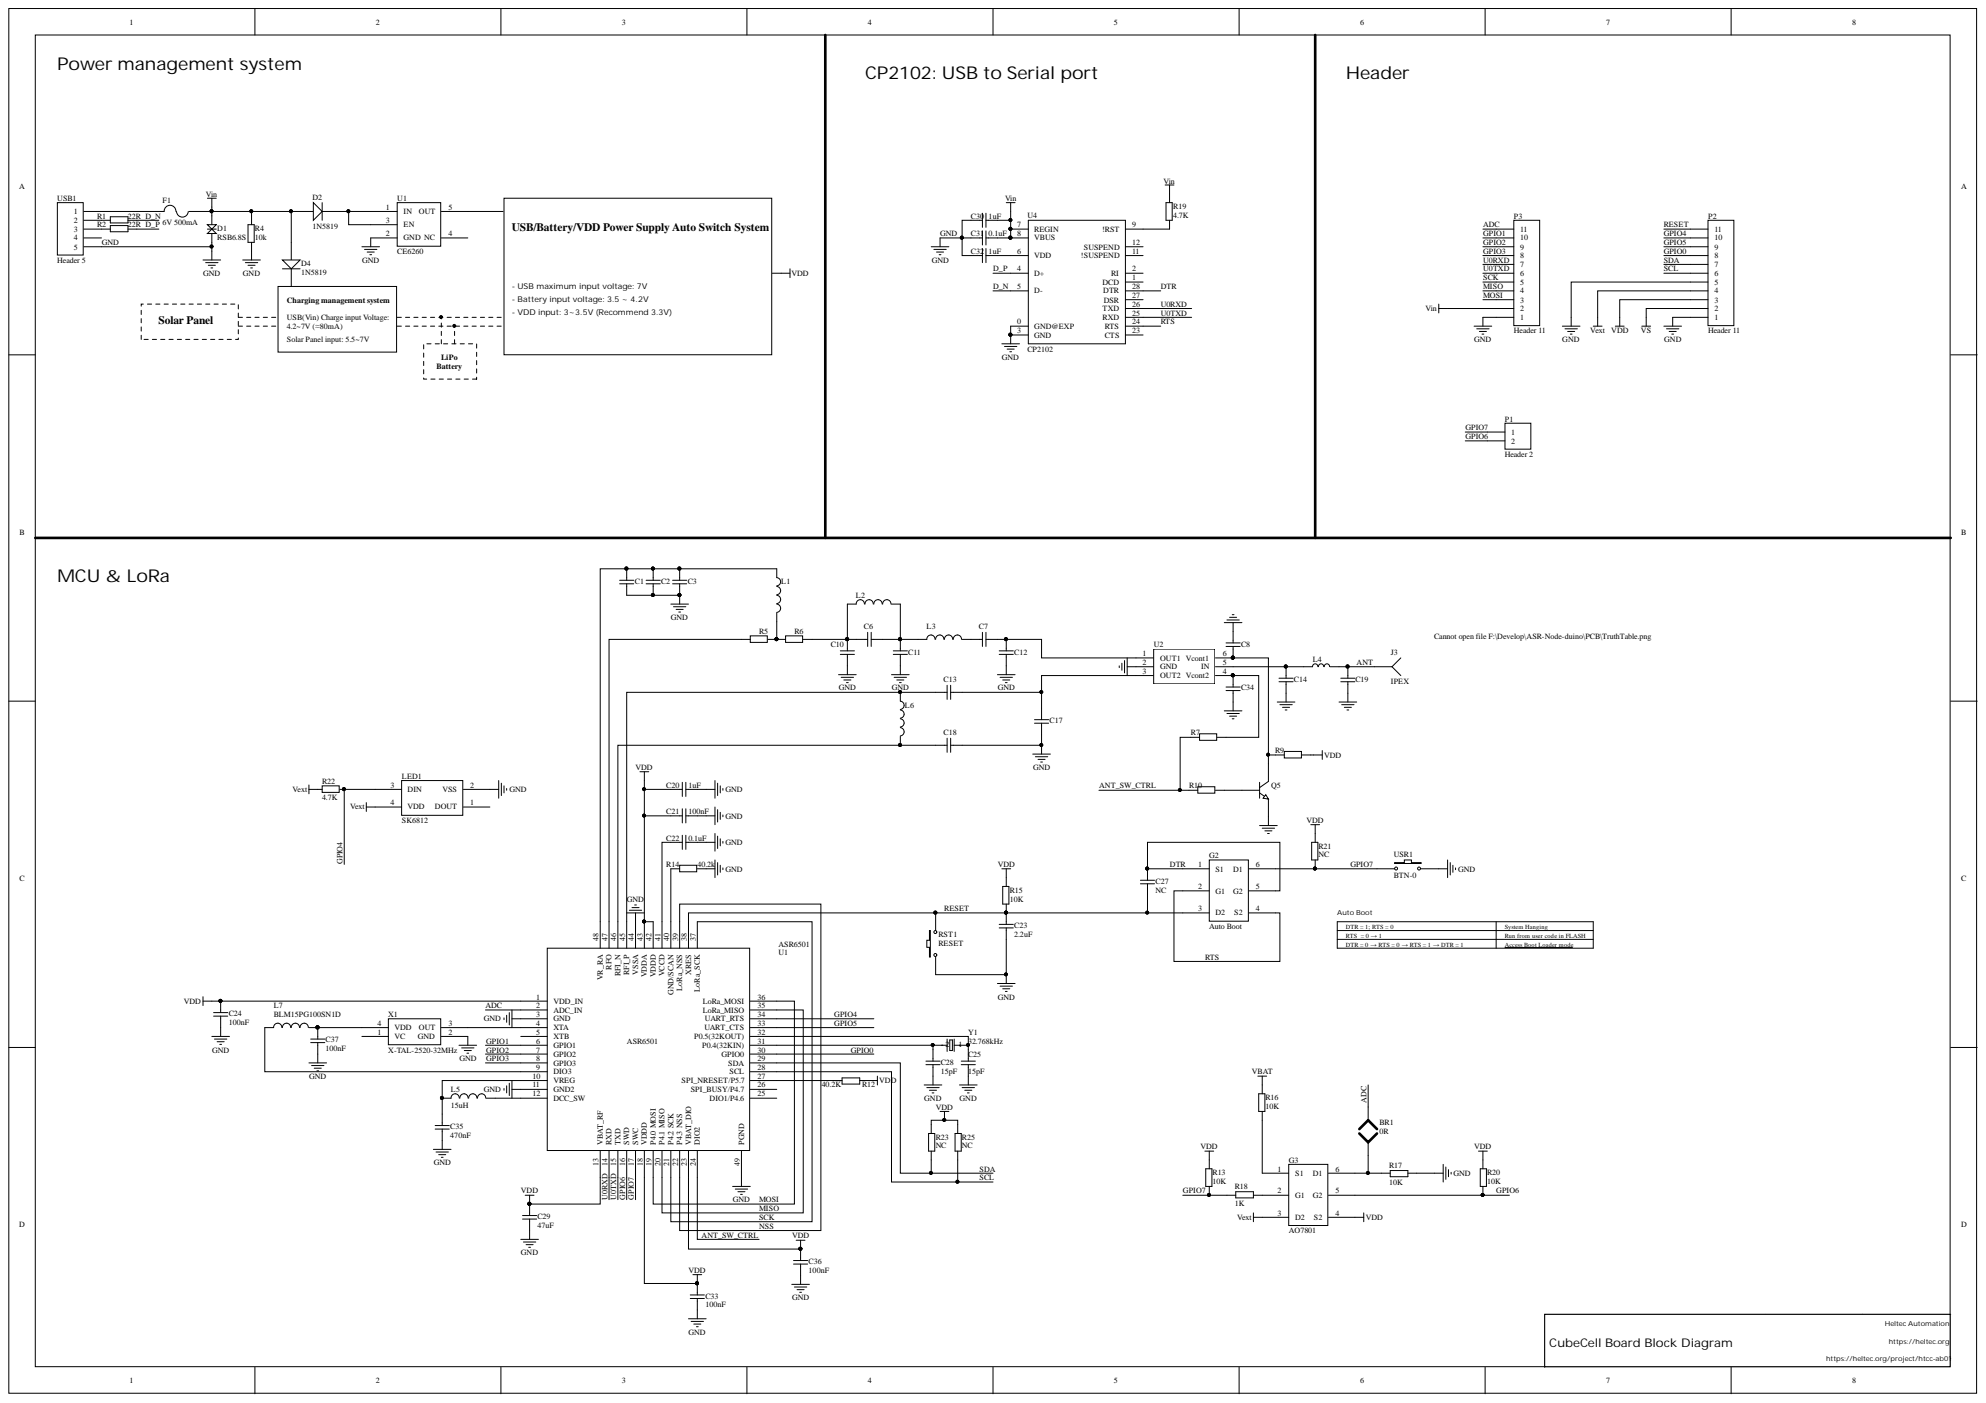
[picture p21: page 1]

USB/Battery/VDD Power Supply Auto Switch System

- USB maximum input voltage: 7V
- Battery input voltage: 3.5 ~ 4.2V
- VDD input: 3~3.5V (Recommend 3.3V)

USB(Vin) Charge input Voltage:
Solar Panel input: 5.5~7V

Cannot open file F:\Develop\ASR-Node-duino\PCB\TruthTable.png

VDD

VDD 4

LoRa_SCK 37 XRES 38 LoRa_NSS 39 GND/SCAN 40 VCCD 41 VDDD 42 VDDA 43 VSSA 44 RFI_P 45 RFI_N 46 RFO 47 VR_RA 48

RTS = 0 → 1 | Run from user code in FLASH

15uH | GND2 11

SCK
NSS

ANT_SW_CTRL

Title CubeCell Board Block Diagram | * * * * * | Heltec Automation https://heltec.org

CubeCell Board Block Diagram Size: A2 | Number: * | Revision: V1.0

Date: 2019/12/13 Time: 18:01:26 | | Sheet * of *
File: E:\DreamSpark\ASR-Node-duino\PCB\Board\V1.1\Cubecell Board Block Diagram.SchDoc

https://heltec.org/project/htcc-ab01

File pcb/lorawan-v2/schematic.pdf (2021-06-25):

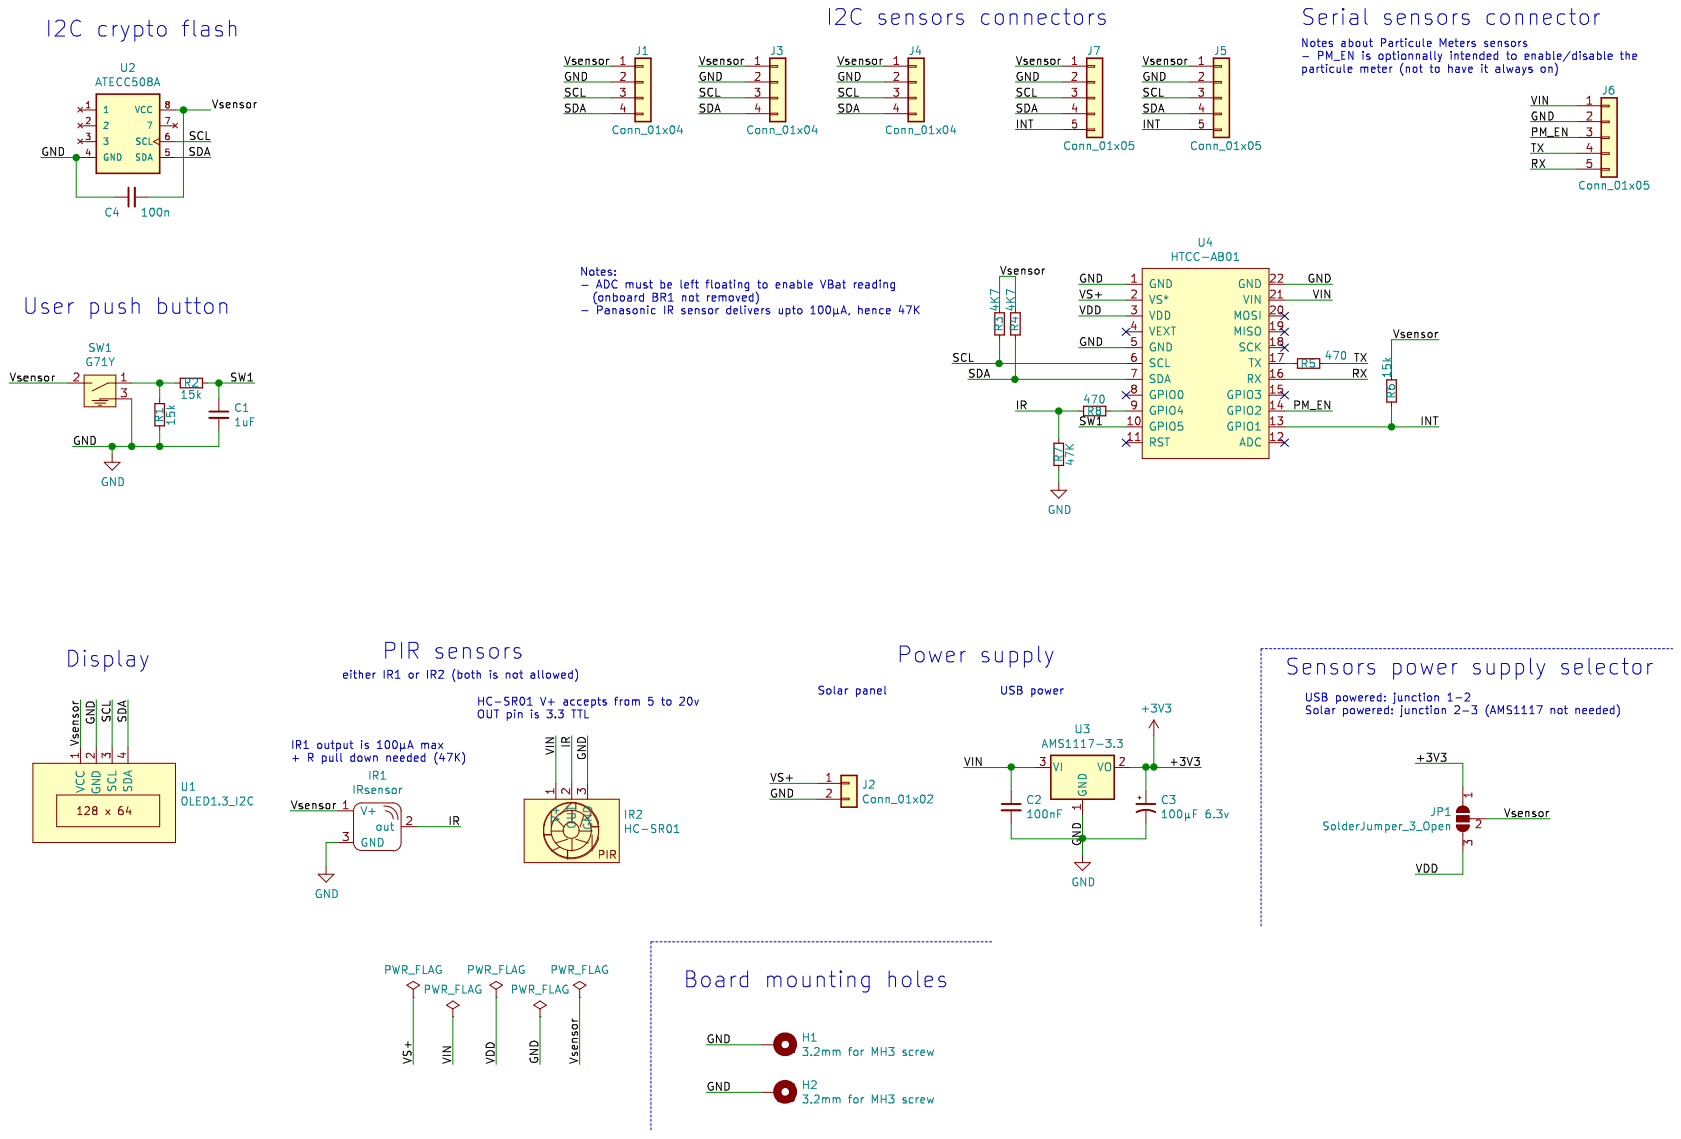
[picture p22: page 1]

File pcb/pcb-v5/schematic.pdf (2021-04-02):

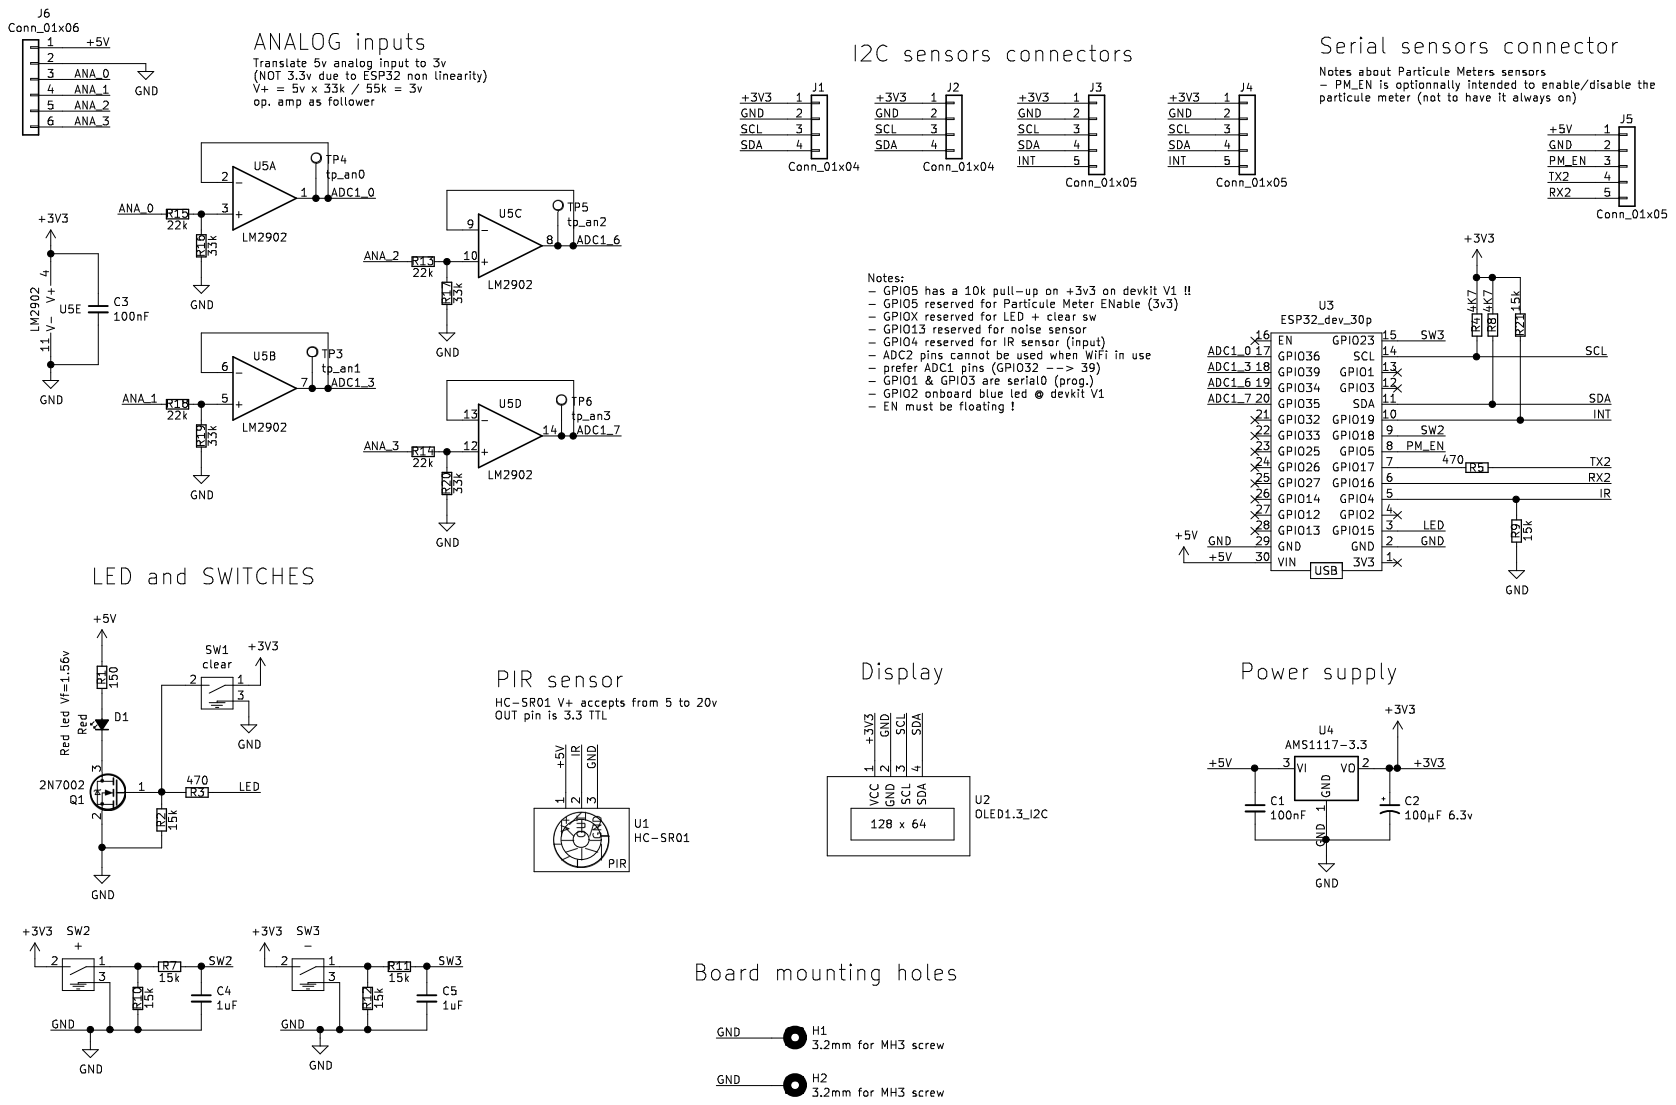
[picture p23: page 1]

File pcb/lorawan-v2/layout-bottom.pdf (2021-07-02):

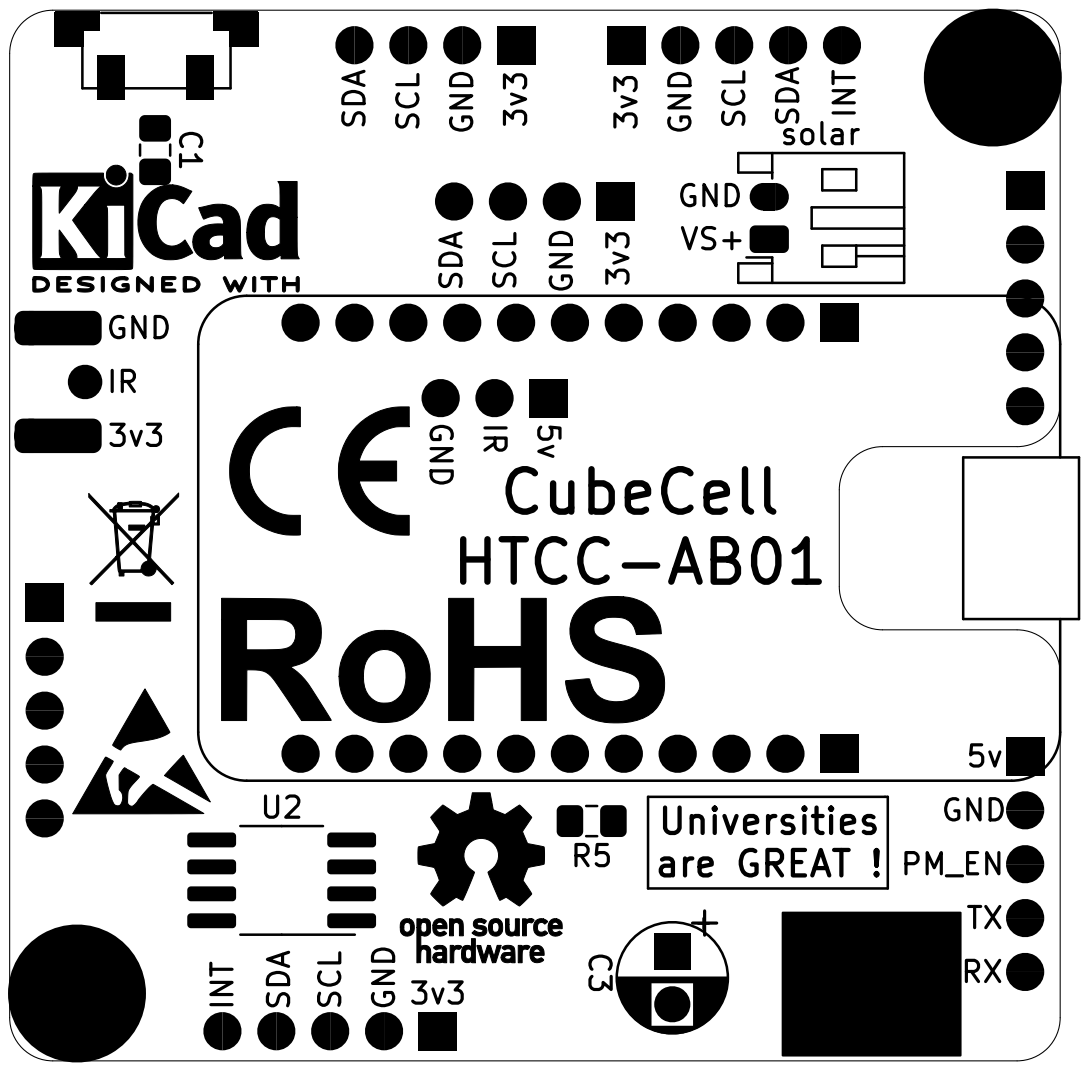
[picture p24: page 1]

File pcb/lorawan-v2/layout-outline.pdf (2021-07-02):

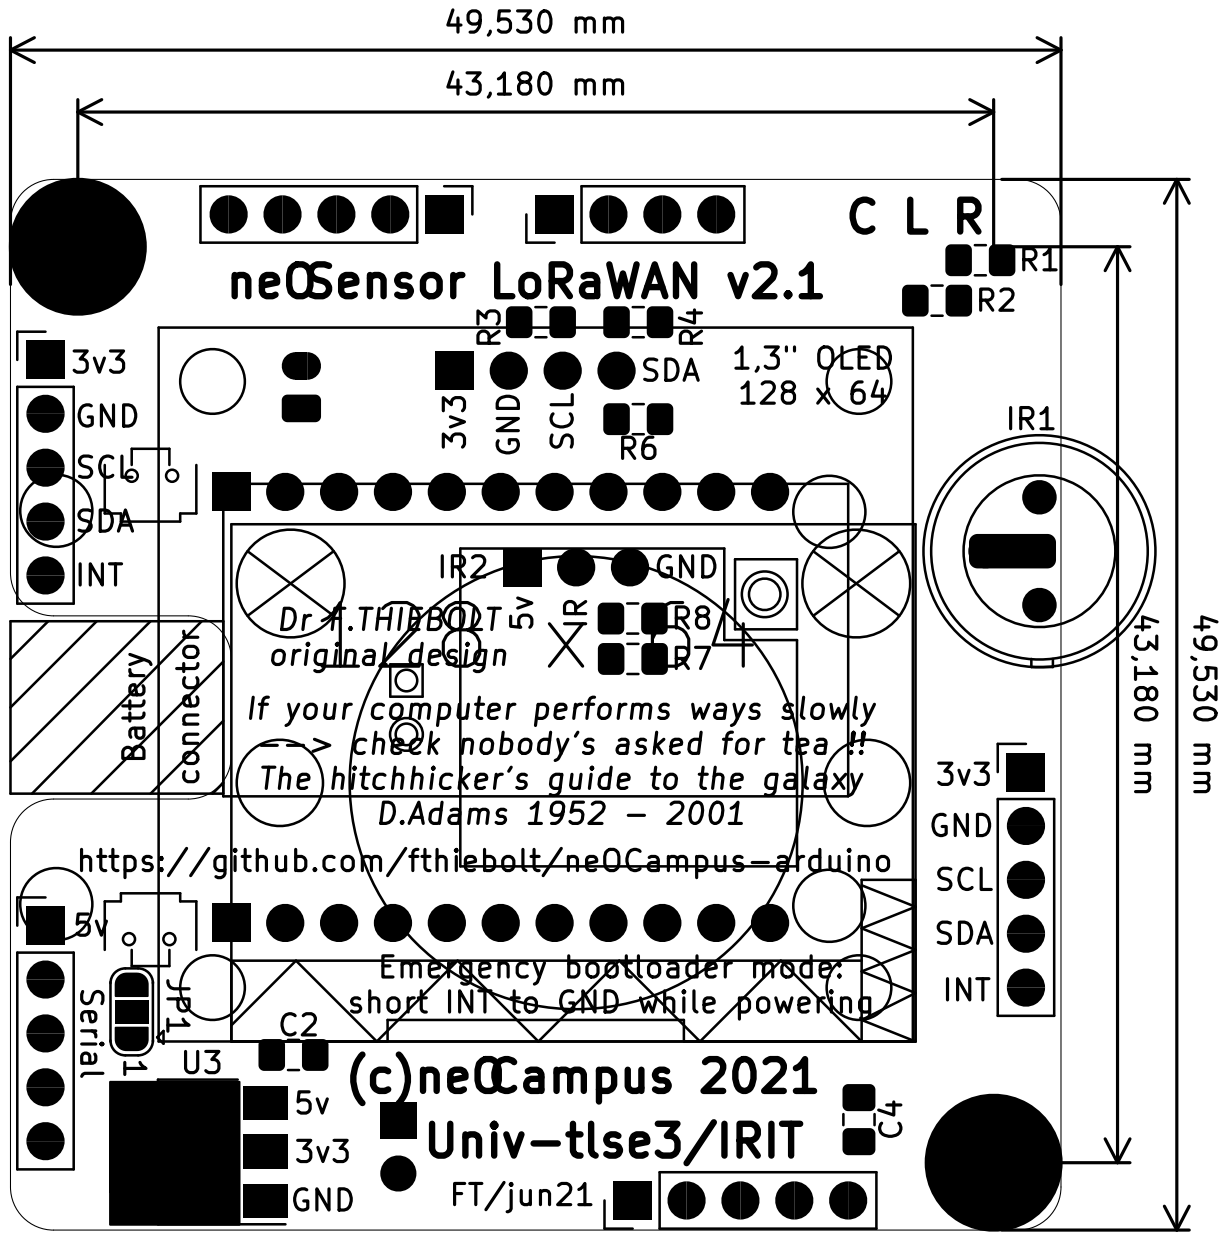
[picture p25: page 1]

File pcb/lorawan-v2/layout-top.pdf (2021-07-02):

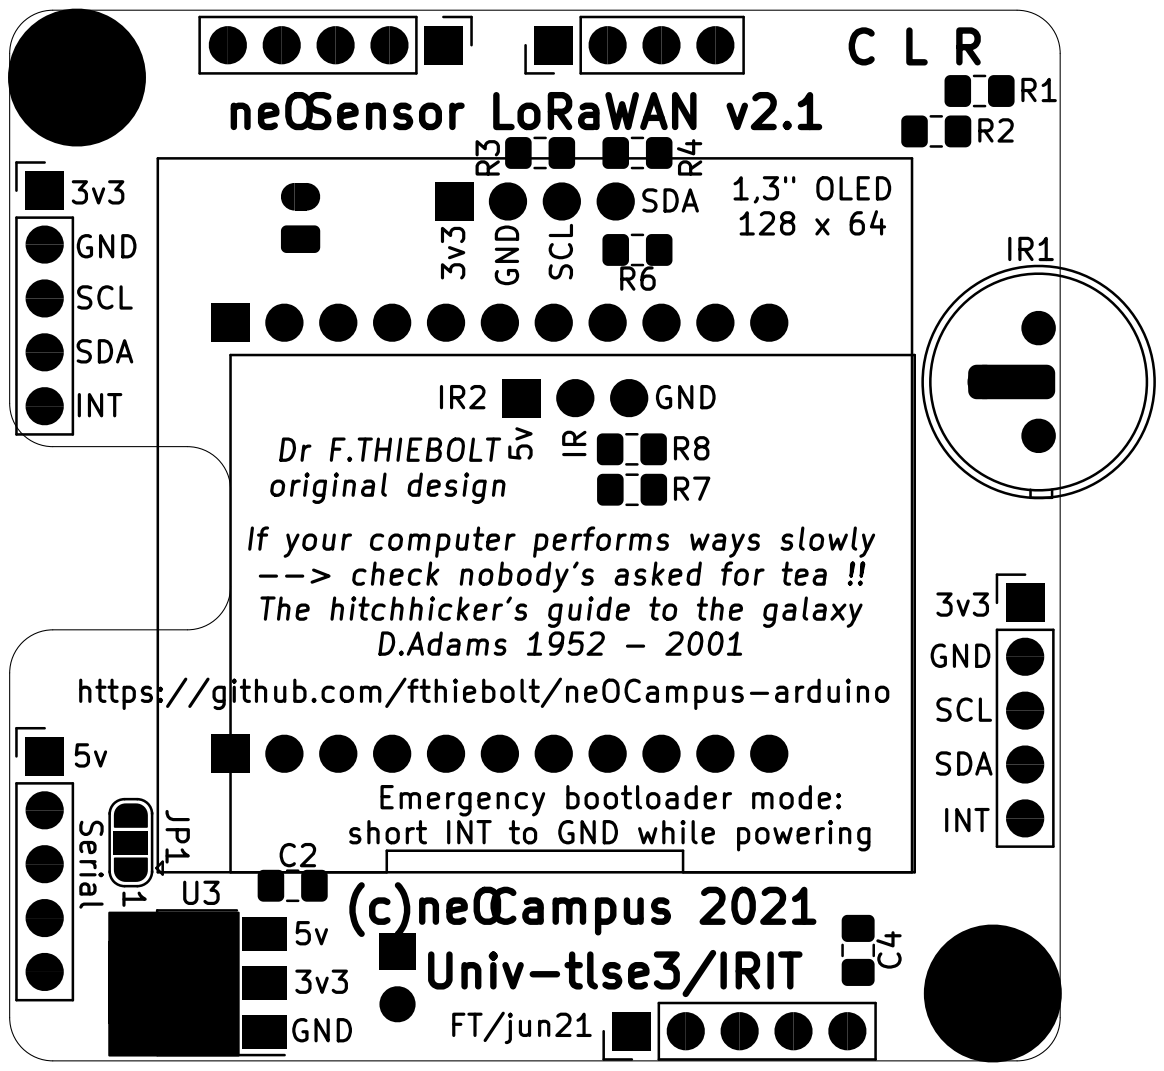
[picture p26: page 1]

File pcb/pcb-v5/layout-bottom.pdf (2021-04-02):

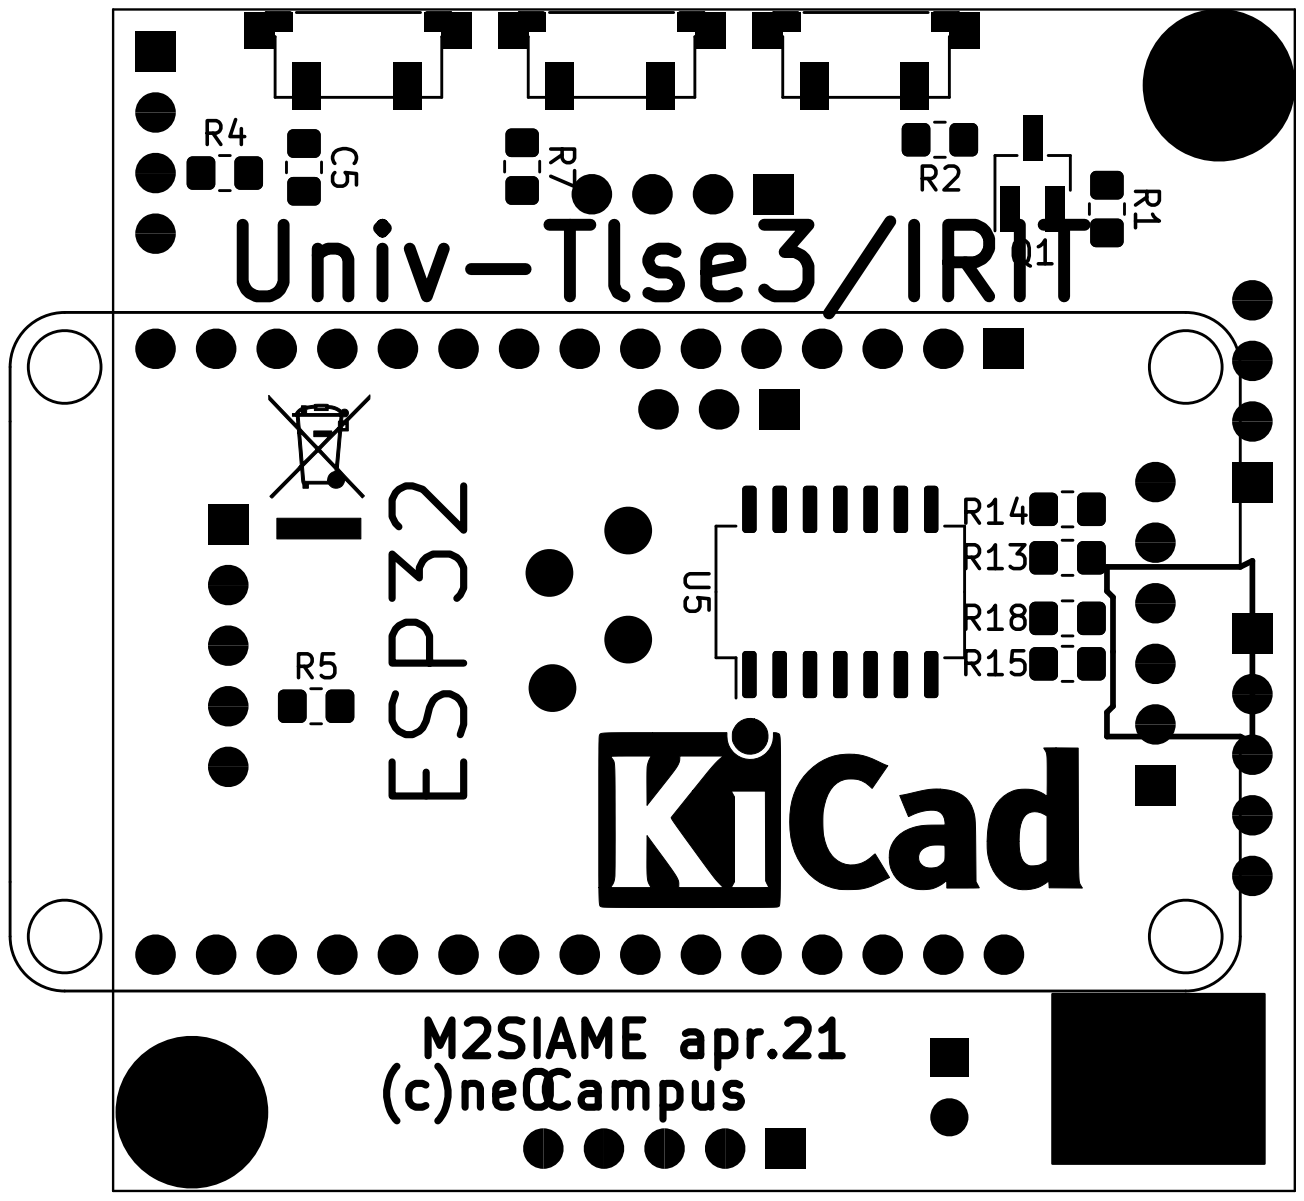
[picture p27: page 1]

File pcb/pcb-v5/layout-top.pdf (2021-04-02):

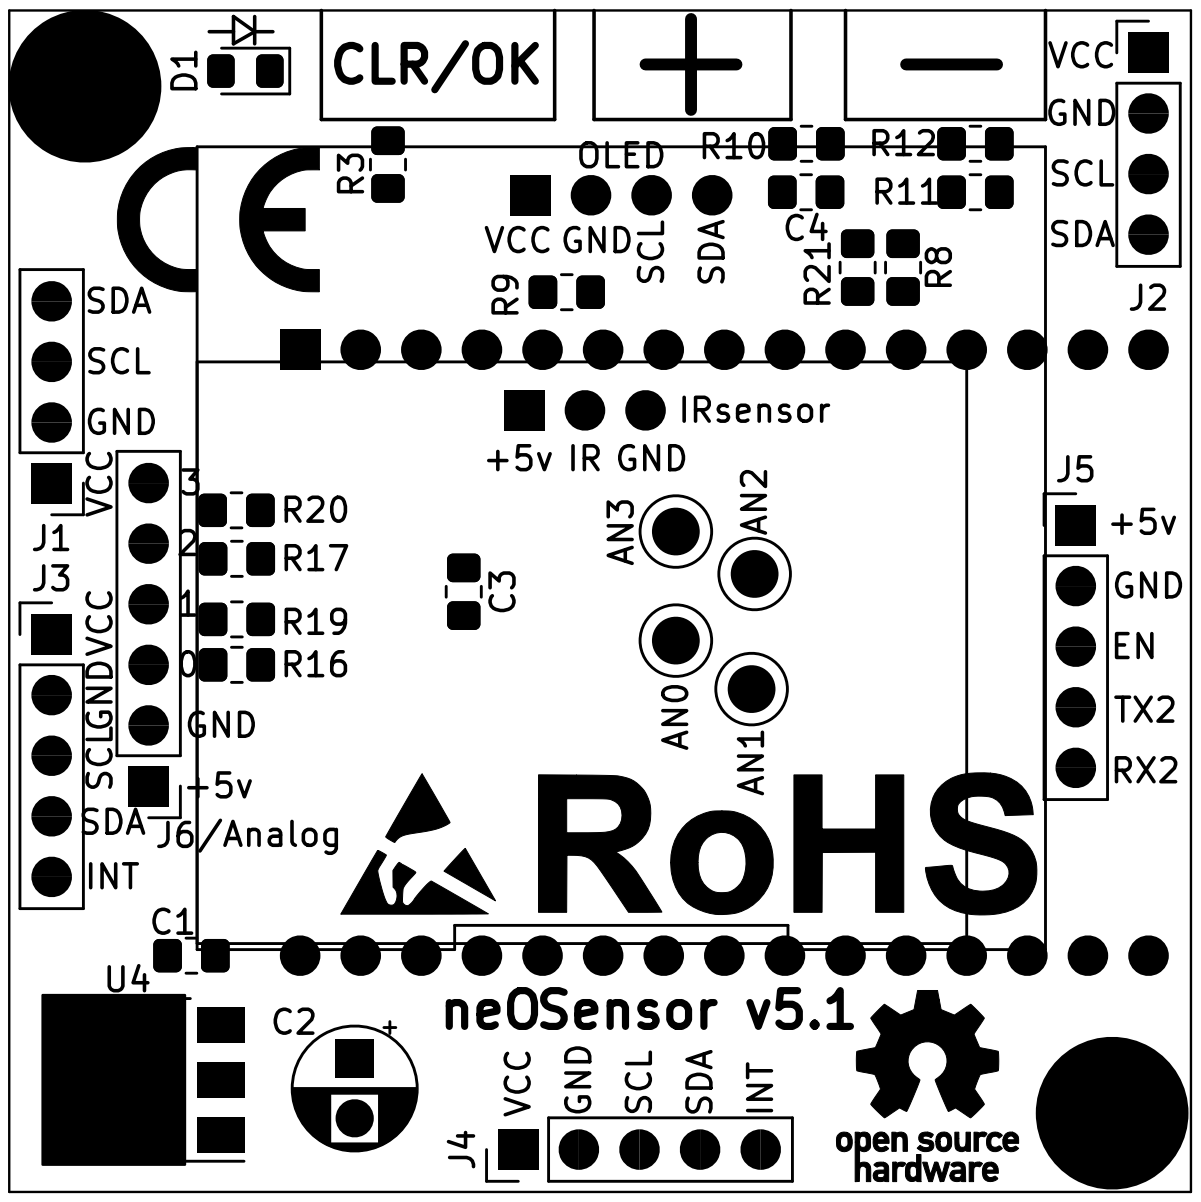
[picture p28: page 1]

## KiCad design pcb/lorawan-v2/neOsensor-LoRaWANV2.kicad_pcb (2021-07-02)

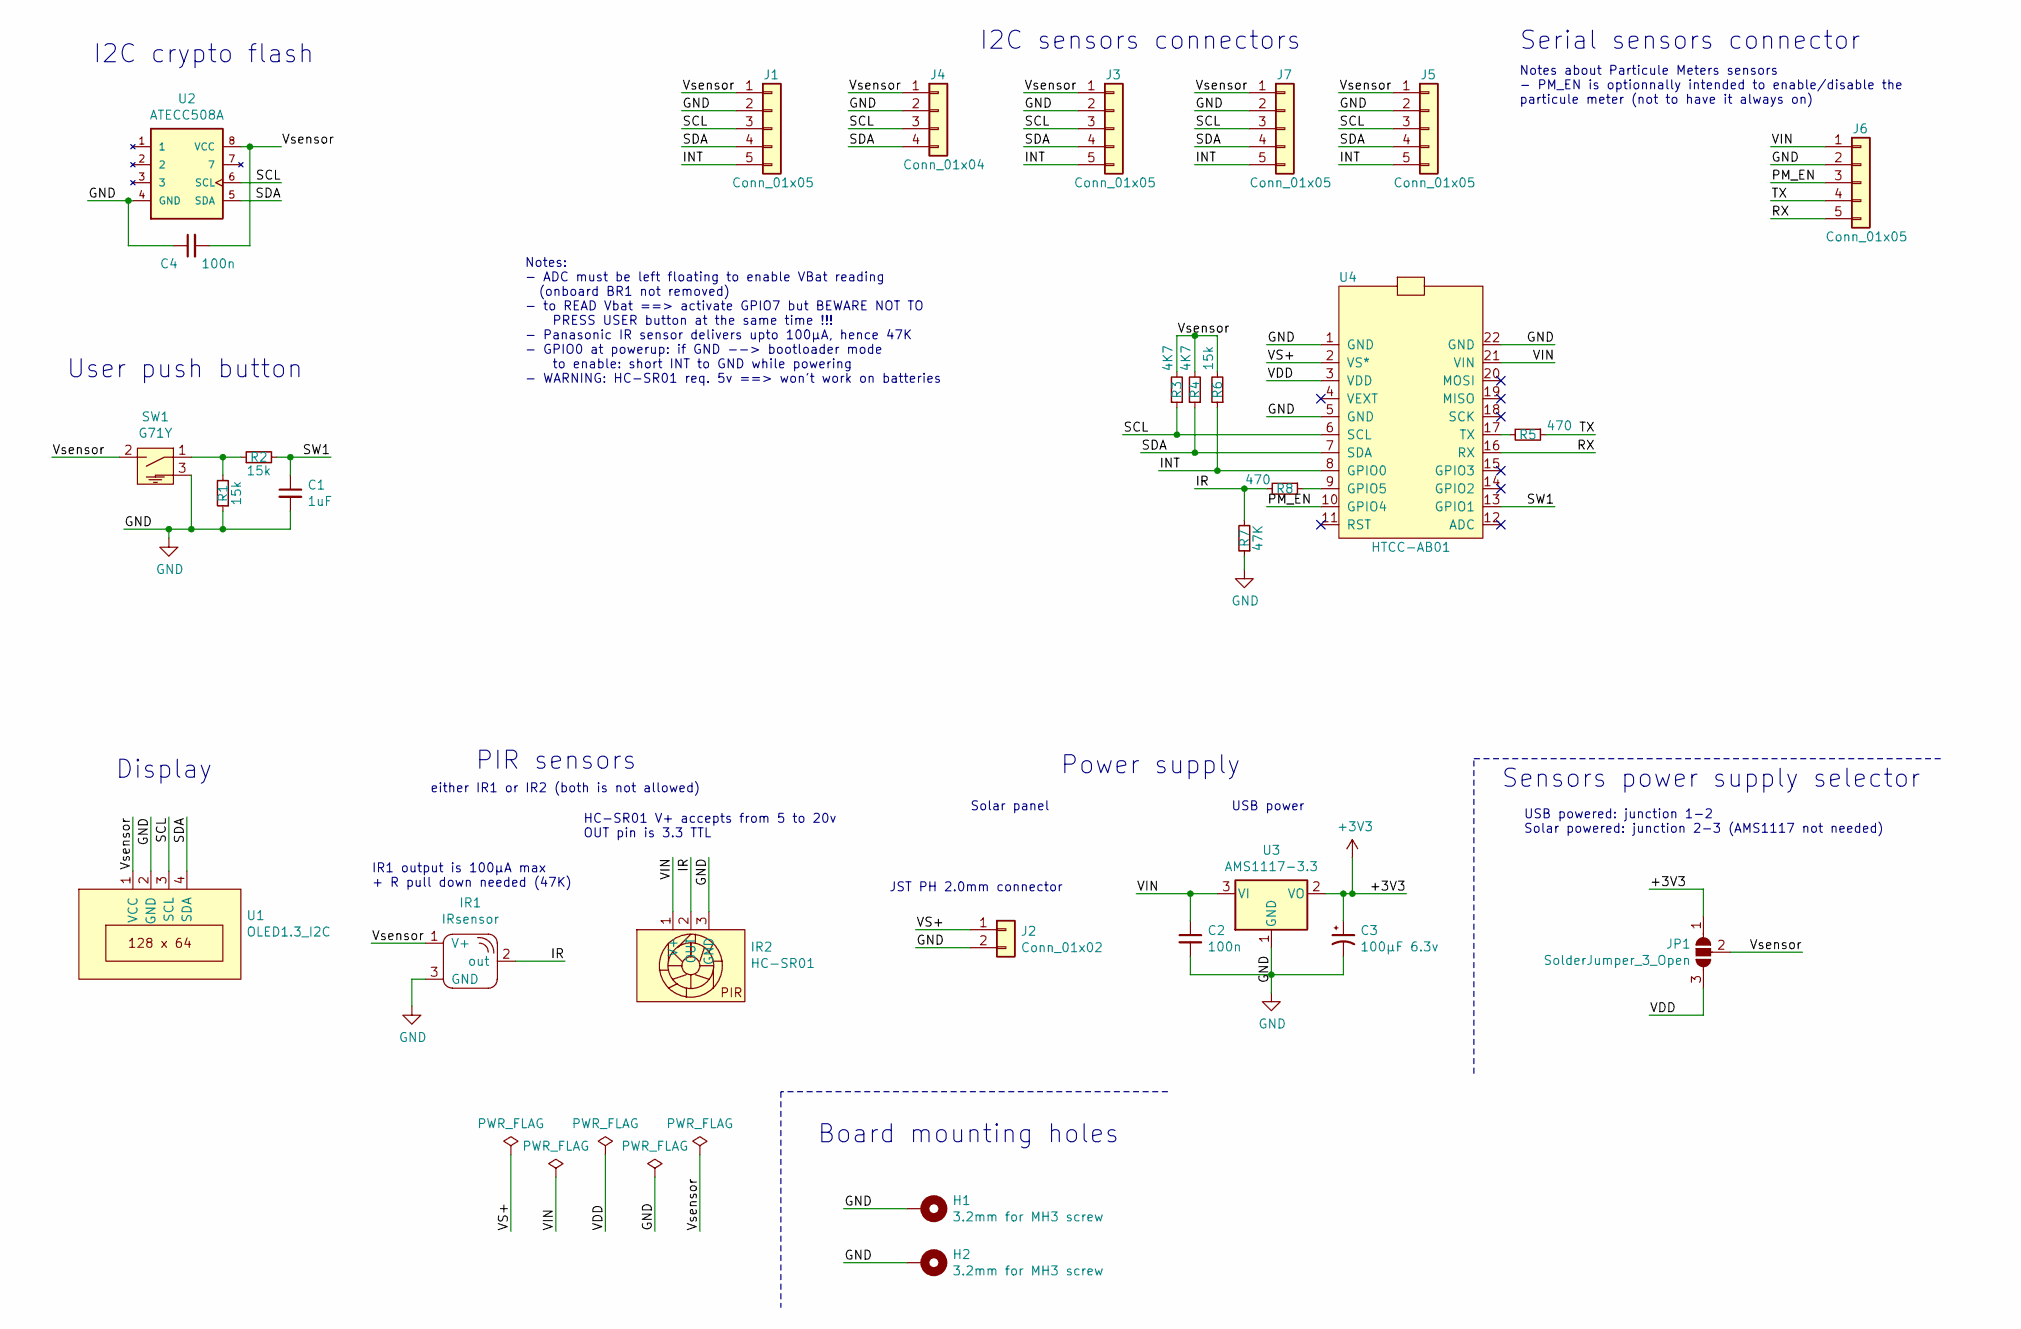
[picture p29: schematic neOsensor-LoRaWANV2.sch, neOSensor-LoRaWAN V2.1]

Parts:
C1: 1uF; C_0805_2012Metric_Pad1.15x1.40mm_HandSolder
C2: 100n; C_0805_2012Metric_Pad1.15x1.40mm_HandSolder
C3: 100µF 6.3v; CP_Radial_D5.0mm_P2.50mm
C4: 100n; C_0805_2012Metric_Pad1.18x1.45mm_HandSolder
H1, H2: 3.2mm for MH3 screw; MountingHole_3.2mm_M3_Pad
IR1: IRsensor; IRsensor_TH_and_smd
IR2: HC-SR01; PIR_HC-SR01
J1, J3, J5, J6, J7: Conn_01x05; PinHeader_1x05_P2.54mm_Vertical
J2: Conn_01x02; JST_PH_S2B-PH-K_1x02_P2.00mm_Horizontal
J4: Conn_01x04; PinHeader_1x04_P2.54mm_Vertical
JP1: SolderJumper_3_Open; SolderJumper-3_P1.3mm_Open_RoundedPad1.0x1.5mm
R1, R2, R6: 15k; R_0805_2012Metric_Pad1.15x1.40mm_HandSolder
R3, R4: 4K7; R_0805_2012Metric_Pad1.15x1.40mm_HandSolder
R5, R8: 470; R_0805_2012Metric_Pad1.15x1.40mm_HandSolder
R7: 47K; R_0805_2012Metric_Pad1.15x1.40mm_HandSolder
SW1: G71Y; G71Y_µsw_smd
U1: OLED1.3_I2C
U2: ATECC508A; SOIC-8_3.9x5.4mm_P1.27mm_HandSolder
U3: AMS1117-3.3; SOT-223-3_TabPin2
U4: HTCC-AB01

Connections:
+3V3: C3.1, JP1.1 (A), U3.2 (VO)
/INT: J1.5, J3.5, J5.5, J7.5, R6.1, U4.8 (GPIO0)
/IR: IR1.2 (out), IR2.2 (OUT), R7.2, R8.2
/PM_EN: J6.3, U4.10 (GPIO4)
/RX: J6.5, U4.16 (RX)
/SCL: J1.3, J3.3, J4.3, J5.3, J7.3, R3.1, U1.3 (SCL), U2.6 (SCL), U4.6 (SCL)
/SDA: J1.4, J3.4, J4.4, J5.4, J7.4, R4.1, U1.4 (SDA), U2.5 (SDA), U4.7 (SDA)
/SW1: C1.1, R2.2, U4.13 (GPIO1)
/TX: J6.4, R5.1
/VDD: JP1.3 (B), U4.3 (VDD)
/VIN: C2.1, IR2.1 (V+), J6.1, U3.3 (VI), U4.21 (VIN)
/VS+: J2.1, U4.2 (VS*)
/Vsensor: C4.2, IR1.1 (V+), J1.1, J3.1, J4.1, J5.1, J7.1, JP1.2 (C), R3.2, R4.2, R6.2, SW1.2, U1.1 (VCC), U2.8 (VCC)
GND: C1.2, C2.2, C3.2, C4.1, H1.1, H2.1, IR1.3 (GND), IR2.3 (GND), J1.2, J2.2, J3.2, J4.2, J5.2, J6.2, J7.2, R1.1, R7.1, SW1.3, U1.2 (GND), U2.4 (GND), U3.1 (GND), U4.1 (GND), U4.5 (GND), U4.22 (GND)
unnamed: R1.2, R2.1, SW1.1
unnamed: R5.2, U4.17 (TX)
unnamed: R8.1, U4.9 (GPIO5)

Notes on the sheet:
User push button
I2C crypto flash
I2C sensors connectors
Serial sensors connector
Board mounting holes
Display
Power supply
Notes: - ADC must be left floating to enable VBat reading (onboard BR1 not removed) - to READ Vbat ==> activate GPIO7 but BEWARE NOT TO PRESS USER button at the same time !!! - Panasonic IR sensor delivers upto 100µA, hence 47K - GPIO0 at powerup: if GND --> bootloader mode to enable: short INT to 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
Notes about Particule Meters sensors - PM_EN is optionnally intended to enable/disable the particule meter (not to have it always on)
PIR sensors
HC-SR01 V+ accepts from 5 to 20v OUT pin is 3.3 TTL
either IR1 or IR2 (both is not allowed)
IR1 output is 100µA max + R pull down needed (47K)
Sensors power supply selector
USB powered: junction 1-2 Solar powered: junction 2-3 (AMS1117 not needed)
USB power
Solar panel
JST PH 2.0mm connector

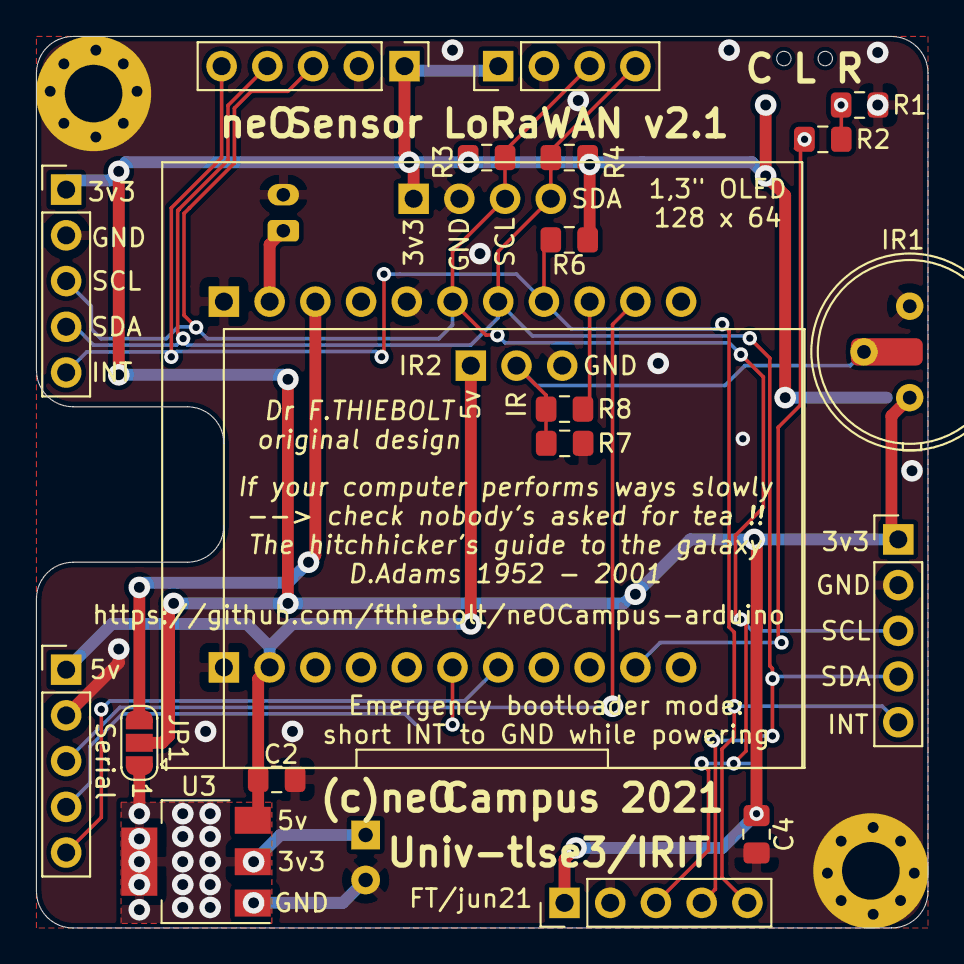
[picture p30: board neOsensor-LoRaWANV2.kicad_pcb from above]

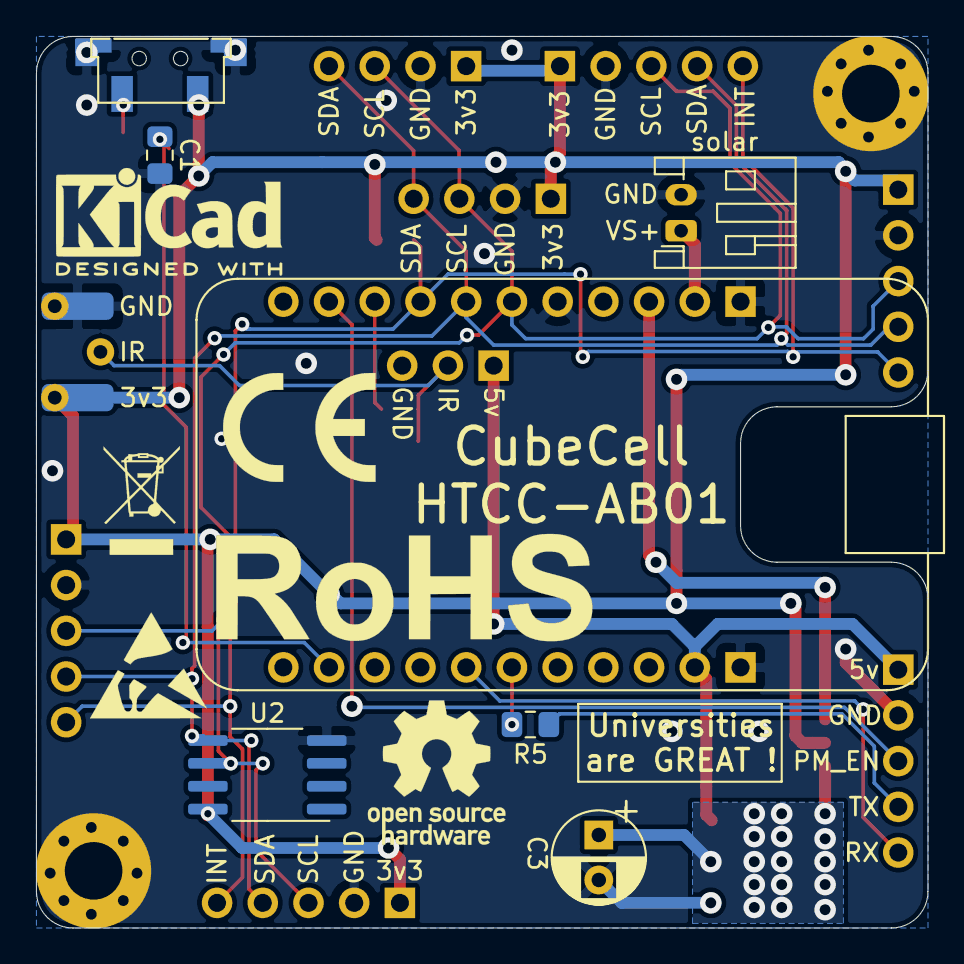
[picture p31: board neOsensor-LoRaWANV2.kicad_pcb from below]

Board: 2 copper layers, 49.5 x 49.5 mm, 29 parts (7 on the bottom side), 17 nets.

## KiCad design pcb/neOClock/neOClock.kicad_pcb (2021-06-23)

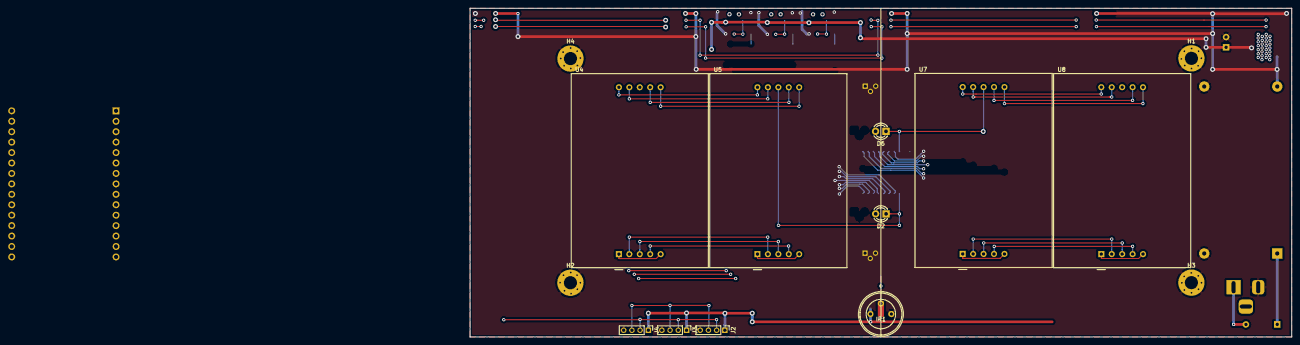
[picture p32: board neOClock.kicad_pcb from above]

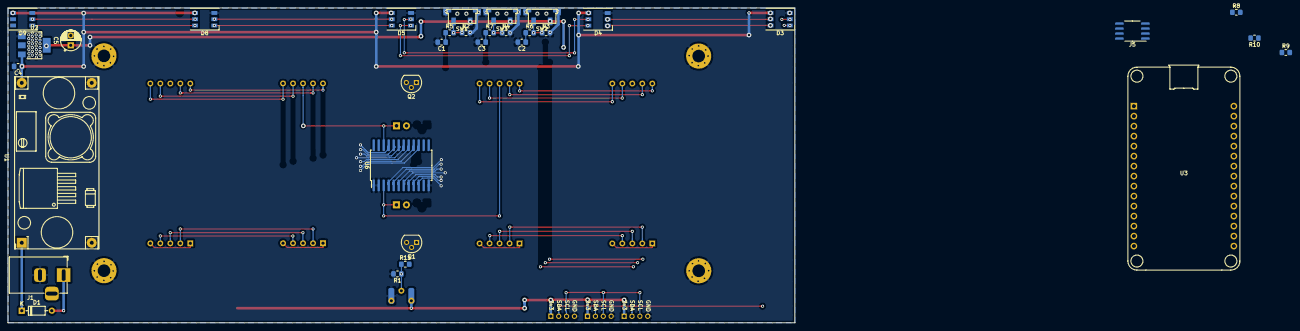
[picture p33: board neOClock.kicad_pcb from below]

Board: 2 copper layers, 200.0 x 80.0 mm, 47 parts (33 on the bottom side), 46 nets.

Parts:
C1, C2, C3: 1µF; R_0805_2012Metric_Pad1.20x1.40mm_HandSolder
C4: 100nF; R_0805_2012Metric_Pad1.20x1.40mm_HandSolder
C5: 100µF; CP_Radial_D5.0mm_P2.50mm
D1: 1N4148; D_DO-35_SOD27_P7.62mm_Horizontal
D2, D6: LED; LED_D3.0mm
D3, D4, D5, D8, D9: APA102; LED_WS2812_PLCC6_5.0x5.0mm_P1.6mm
H1, H2, H3, H4: MountingHole_Pad; MountingHole_3.2mm_M3_Pad
IR1: IRsensor; IRsensor_TH_and_smd
J1: Barrel_Jack; BarrelJack_Horizontal
J2, J3, J4: Conn_01x04; PinHeader_1x04_P2.00mm_Vertical
J5: ATECC508A; SOIC-8_3.9x5.4mm_P1.27mm_HandSolder
Q1, Q2: 2n2222a; TO-92
R1: 47k; R_0805_2012Metric_Pad1.20x1.40mm_HandSolder
R2, R3, R4, R5, R6, R7: 15K; R_0805_2012Metric_Pad1.20x1.40mm_HandSolder
R8, R9: 4.7K; R_0805_2012Metric_Pad1.20x1.40mm_HandSolder
R10, R11: 470; R_0805_2012Metric_Pad1.20x1.40mm_HandSolder
SW1, SW2, SW3: G71Y; G71Y_µsw_smd
U1: DCDC_LM2596; DC_DC_LM2596
U2: AMS1117; SOT-223-3_TabPin2
U3: ESP32_dev_30p
U4, U5, U7, U8: SA15-11GWA; SA15-11xxx
U6: SAA1064; SOIC-24W_7.5x15.4mm_P1.27mm_HandSolder

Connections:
0: C1.2, C2.2, C3.2, C4.2, C5.2, D3.3, D4.3, D5.3, D8.3, D9.3, H1.1, H2.1, H3.1, H4.1, IR1.3, J1.2, J2.4, J3.4, J4.4, J5.4, R1.2, R2.2, R3.2, R4.2, SW1.3, SW2.3, SW3.3, U1.2, U1.3, U2.1, U3.2, U3.29, U6.1, U6.2, U6.12
3v3: C5.1, IR1.1, J2.1, J3.1, J4.1, J5.8, R8.2, R9.2, SW1.2, SW2.2, SW3.2, U2.2
5v: C4.1, D3.4, D4.4, D5.4, D8.4, D9.4, U1.4, U2.3, U3.30
12v: D1.1, Q1.1, Q2.1, U1.1, U6.13
/a1_5: Q1.2, U6.11
/a2: U4.2, U5.2, U6.6
/a3: U4.3, U5.3, U6.7
/a4: U4.4, U5.4, U6.8
/a6: U4.6, U5.6, U6.9
/a7: U4.7, U5.7, U6.10
/a8: D2.1, U5.8, U6.3
/a9: U4.9, U5.9, U6.5
/a10: U4.10, U5.10, U6.4
/b1_5: Q2.2, U6.14
/b2: U6.19, U7.2, U8.2
/b3: U6.18, U7.3, U8.3
/b4: U6.17, U7.4, U8.4
/b6: U6.16, U7.6, U8.6
/b7: U6.15, U7.7, U8.7
/b8: D6.1, U6.22, U7.8
/b9: U6.20, U7.9, U8.9
/b10: U6.21, U7.10, U8.10
CI: D3.2, U3.9
DI: D3.1, U3.15
IR: R11.2, U3.5
unnamed: D1.2, J1.1
unnamed: D2.2, Q1.3, U4.1, U4.5, U7.1, U7.5
unnamed: D3.5, D4.2
unnamed: D3.6, D4.1
unnamed: D4.5, D5.2
unnamed: D4.6, D5.1
unnamed: D5.5, D8.2
unnamed: D5.6, D8.1
unnamed: D6.2, Q2.3, U5.1, U5.5, U8.1, U8.5
unnamed: D8.5, D9.2
unnamed: D8.6, D9.1
unnamed: IR1.2, R1.1, R11.1
unnamed: R2.1, R5.2, SW1.1
unnamed: R3.1, R6.2, SW2.1
unnamed: R4.1, R7.2, SW3.1
unnamed: R10.2, U3.13
Push_1: C1.1, R5.1, U3.17
Push_2: C2.1, R6.1, U3.18
Push_3: C3.1, R7.1, U3.19
SCL: J2.3, J3.3, J4.3, J5.6, R8.1, U3.14, U6.24
SDA: J2.2, J3.2, J4.2, J5.5, R9.1, U3.11, U6.23

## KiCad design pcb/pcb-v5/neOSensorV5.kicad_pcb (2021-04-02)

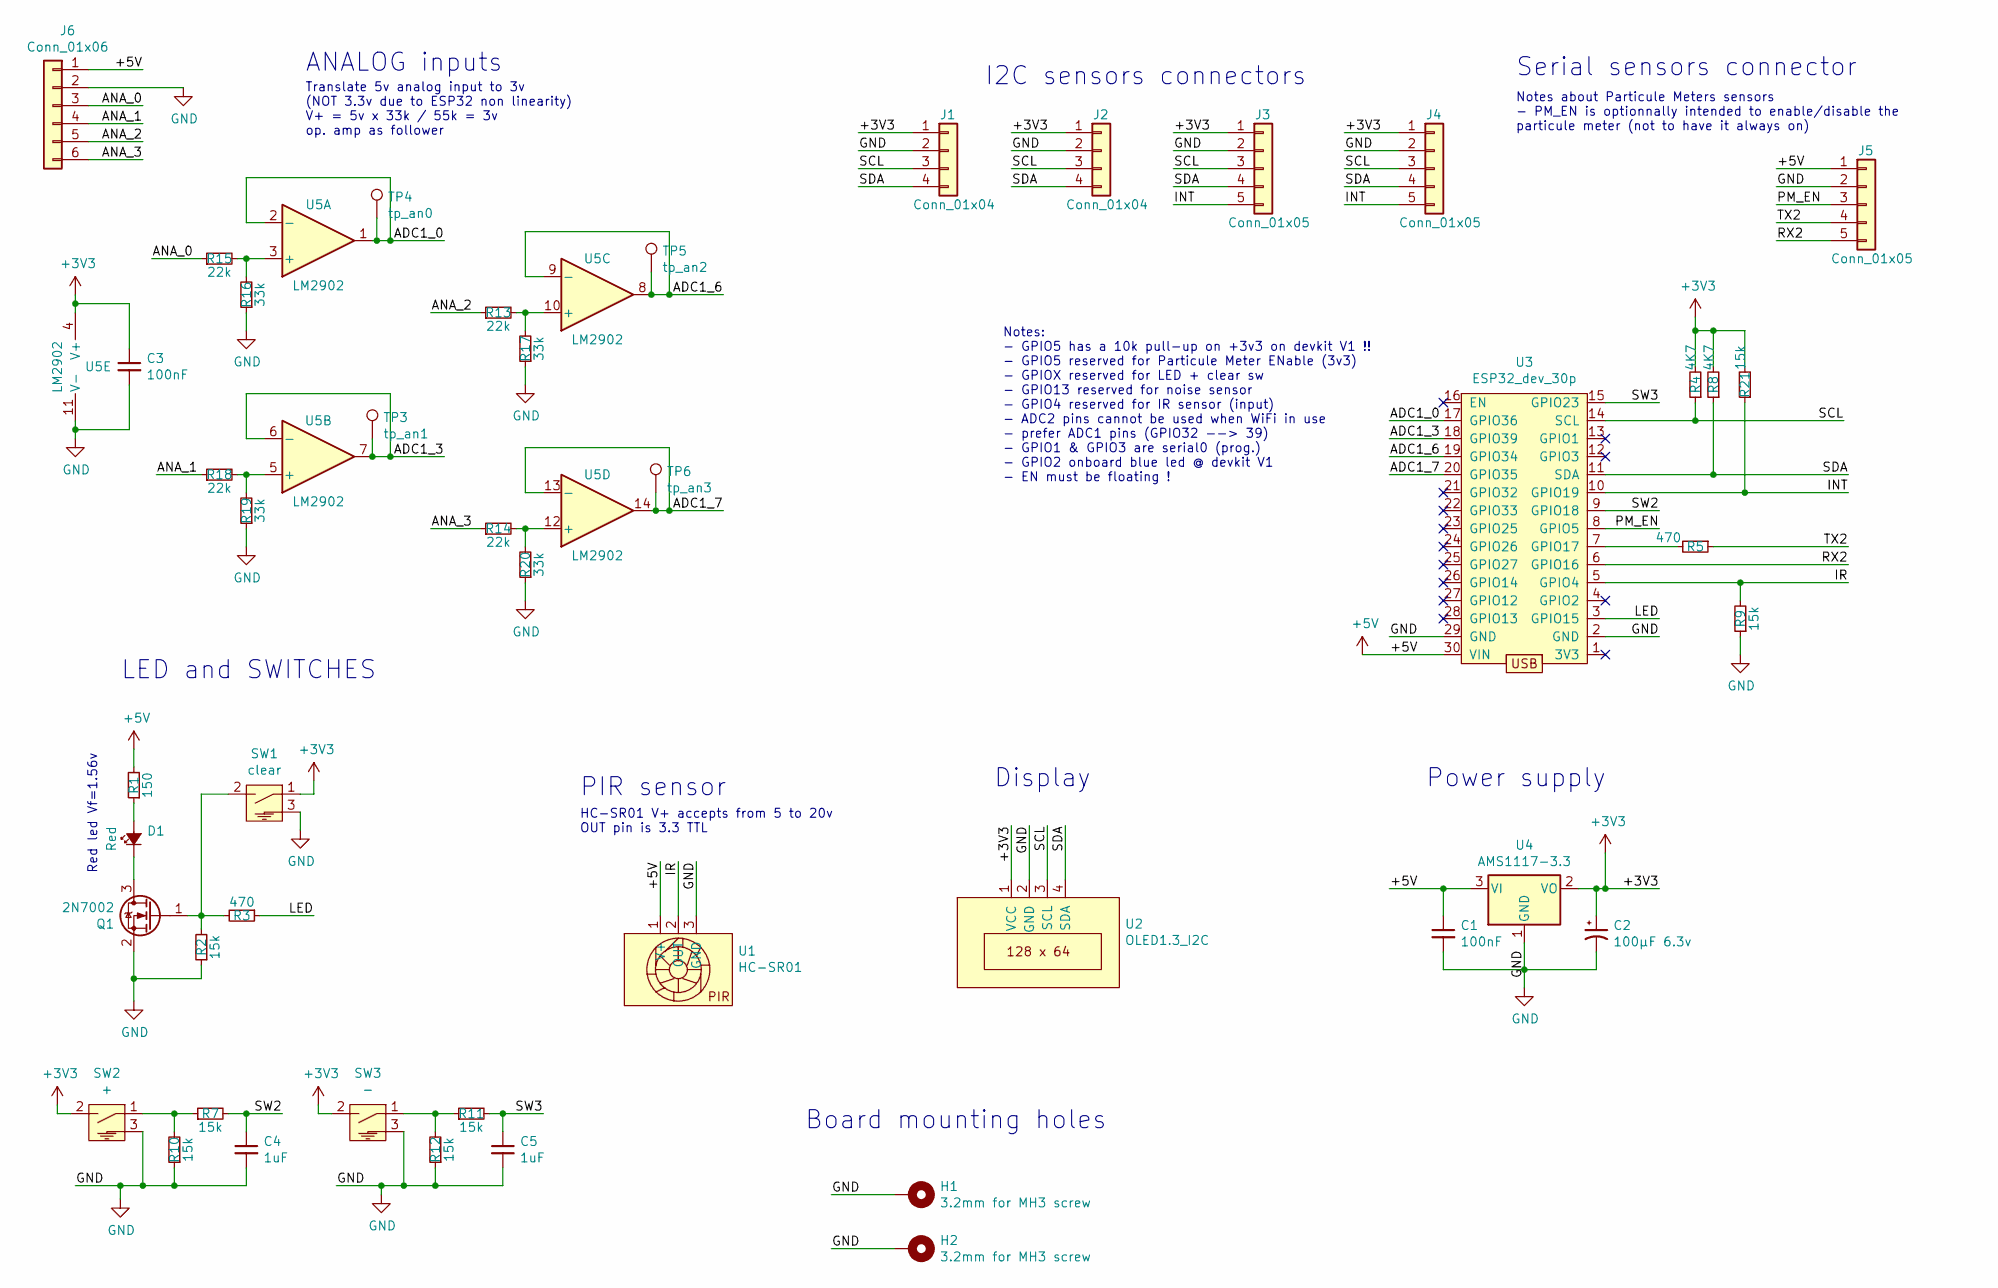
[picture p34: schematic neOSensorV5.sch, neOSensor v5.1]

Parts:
C1, C3: 100nF; R_0805_2012Metric_Pad1.20x1.40mm_HandSolder
C2: 100µF 6.3v; CP_Radial_D5.0mm_P2.50mm
C4, C5: 1uF; R_0805_2012Metric_Pad1.20x1.40mm_HandSolder
D1: Red; LED_0805_2012Metric_Pad1.15x1.40mm_HandSolder
H1, H2: 3.2mm for MH3 screw; MountingHole_3.2mm_M3_Pad
J1, J2: Conn_01x04; PinHeader_1x04_P2.54mm_Vertical
J3, J4, J5: Conn_01x05; PinHeader_1x05_P2.54mm_Vertical
J6: Conn_01x06; PinHeader_1x06_P2.54mm_Vertical
Q1: 2N7002; SOT-23_Handsoldering
R1: 150; R_0805_2012Metric_Pad1.20x1.40mm_HandSolder
R2, R7, R9, R10, R11, R12, R21: 15k; R_0805_2012Metric_Pad1.20x1.40mm_HandSolder
R3, R5: 470; R_0805_2012Metric_Pad1.20x1.40mm_HandSolder
R4, R8: 4K7; R_0805_2012Metric_Pad1.20x1.40mm_HandSolder
R13, R14, R15, R18: 22k; R_0805_2012Metric_Pad1.20x1.40mm_HandSolder
R16, R17, R19, R20: 33k; R_0805_2012Metric_Pad1.20x1.40mm_HandSolder
SW1: clear; G71Y_µsw_smd
SW2: +; G71Y_µsw_smd
SW3: -; G71Y_µsw_smd
TP3: tp_an1; TestPoint_Loop_D2.50mm_Drill1.0mm
TP4: tp_an0; TestPoint_Loop_D2.50mm_Drill1.0mm
TP5: tp_an2; TestPoint_Loop_D2.50mm_Drill1.0mm
TP6: tp_an3; TestPoint_Loop_D2.50mm_Drill1.0mm
U1: HC-SR01; PIR_HC-SR01
U2: OLED1.3_I2C
U3: ESP32_dev_30p
U4: AMS1117-3.3; SOT-223-3_TabPin2
U5: LM2902; SO-14_5.3x10.2mm_P1.27mm

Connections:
+3V3: C2.1, C3.1, J1.1, J2.1, J3.1, J4.1, R4.2, R8.2, R21.2, SW1.1, SW2.2, SW3.2, U2.1 (VCC), U4.2 (VO), U5.4 (V+)
+5V: C1.1, J5.1, J6.1, R1.2, U1.1 (V+), U3.30 (VIN), U4.3 (VI)
/ADC1_0: TP4.1, U3.17 (GPIO36), U5.1, U5.2 (-)
/ADC1_3: TP3.1, U3.18 (GPIO39), U5.6 (-), U5.7
/ADC1_6: TP5.1, U3.19 (GPIO34), U5.8, U5.9 (-)
/ADC1_7: TP6.1, U3.20 (GPIO35), U5.13 (-), U5.14
/ANA_0: J6.3, R15.1
/ANA_1: J6.4, R18.1
/ANA_2: J6.5, R13.1
/ANA_3: J6.6, R14.1
/INT: J3.5, J4.5, R21.1, U3.10 (GPIO19)
/IR: R9.2, U1.2 (OUT), U3.5 (GPIO4)
/LED: R3.1, U3.3 (GPIO15)
/PM_EN: J5.3, U3.8 (GPIO5)
/RX2: J5.5, U3.6 (GPIO16)
/SCL: J1.3, J2.3, J3.3, J4.3, R4.1, U2.3 (SCL), U3.14 (SCL)
/SDA: J1.4, J2.4, J3.4, J4.4, R8.1, U2.4 (SDA), U3.11 (SDA)
/SW2: C4.1, R7.2, U3.9 (GPIO18)
/SW3: C5.1, R11.2, U3.15 (GPIO23)
/TX2: J5.4, R5.1
GND: C1.2, C2.2, C3.2, C4.2, C5.2, H1.1, H2.1, J1.2, J2.2, J3.2, J4.2, J5.2, J6.2, Q1.2 (S), R2.1, R9.1, R10.1, R12.1, R16.1, R17.1, R19.1, R20.1, SW1.3, SW2.3, SW3.3, U1.3 (GND), U2.2 (GND), U3.2 (GND), U3.29 (GND), U4.1 (GND), U5.11 (V-)
unnamed: D1.1 (K), Q1.3 (D)
unnamed: D1.2 (A), R1.1
unnamed: Q1.1 (G), R2.2, R3.2, SW1.2
unnamed: R5.2, U3.7 (GPIO17)
unnamed: R7.1, R10.2, SW2.1
unnamed: R11.1, R12.2, SW3.1
unnamed: R13.2, R17.2, U5.10 (+)
unnamed: R14.2, R20.2, U5.12 (+)
unnamed: R15.2, R16.2, U5.3 (+)
unnamed: R18.2, R19.2, U5.5 (+)

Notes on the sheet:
I2C sensors connectors
Serial sensors connector
Board mounting holes
Display
Power supply
Notes: - GPIO5 has a 10k pull-up on +3v3 on devkit V1 !! - GPIO5 reserved for Particule Meter ENable (3v3) - GPIOX reserved for LED + clear sw - GPIO13 reserved for noise sensor - GPIO4 reserved for IR sensor (input) - ADC2 pins cannot be used when WiFi in use - prefer ADC1 pins (GPIO32 --> 39) - G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
Notes about Particule Meters sensors - PM_EN is optionnally intended to enable/disable the particule meter (not to have it always on)
PIR sensor
HC-SR01 V+ accepts from 5 to 20v OUT pin is 3.3 TTL
LED and SWITCHES
ANALOG inputs
Translate 5v analog input to 3v (NOT 3.3v due to ESP32 non linearity) V+ = 5v x 33k / 55k = 3v op. amp as follower
Red led Vf=1.56v

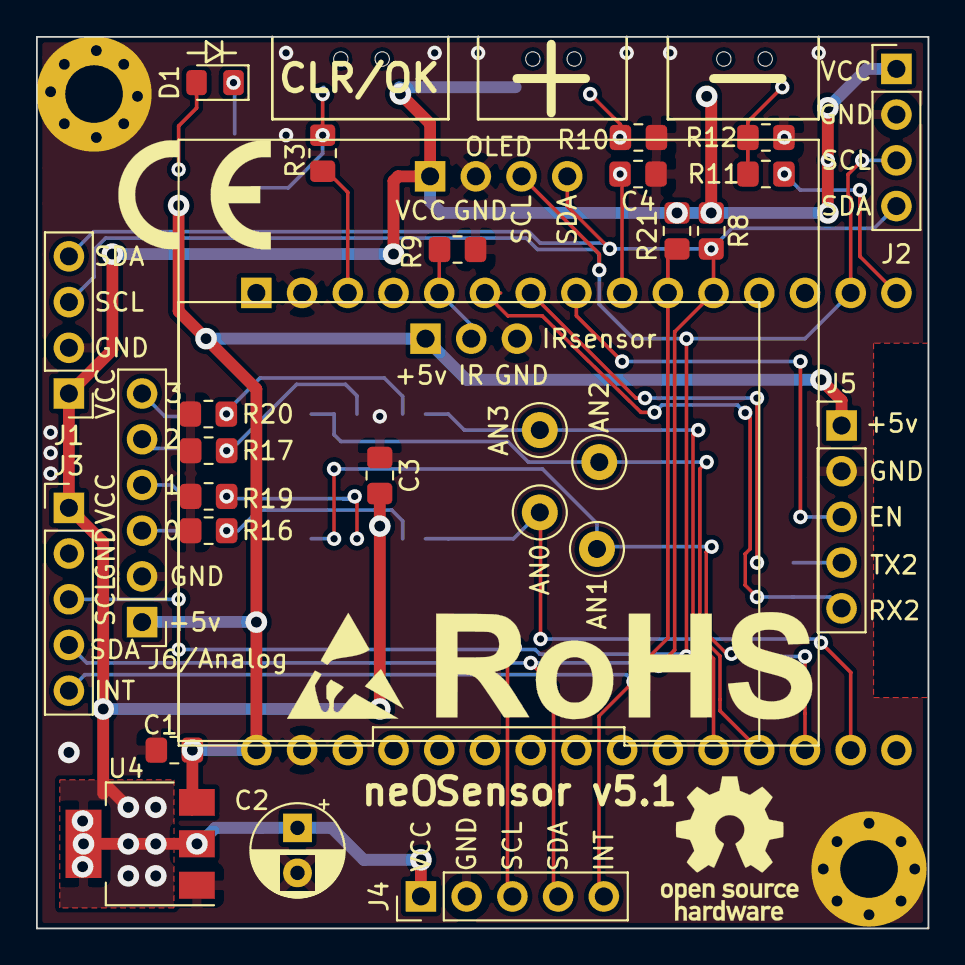
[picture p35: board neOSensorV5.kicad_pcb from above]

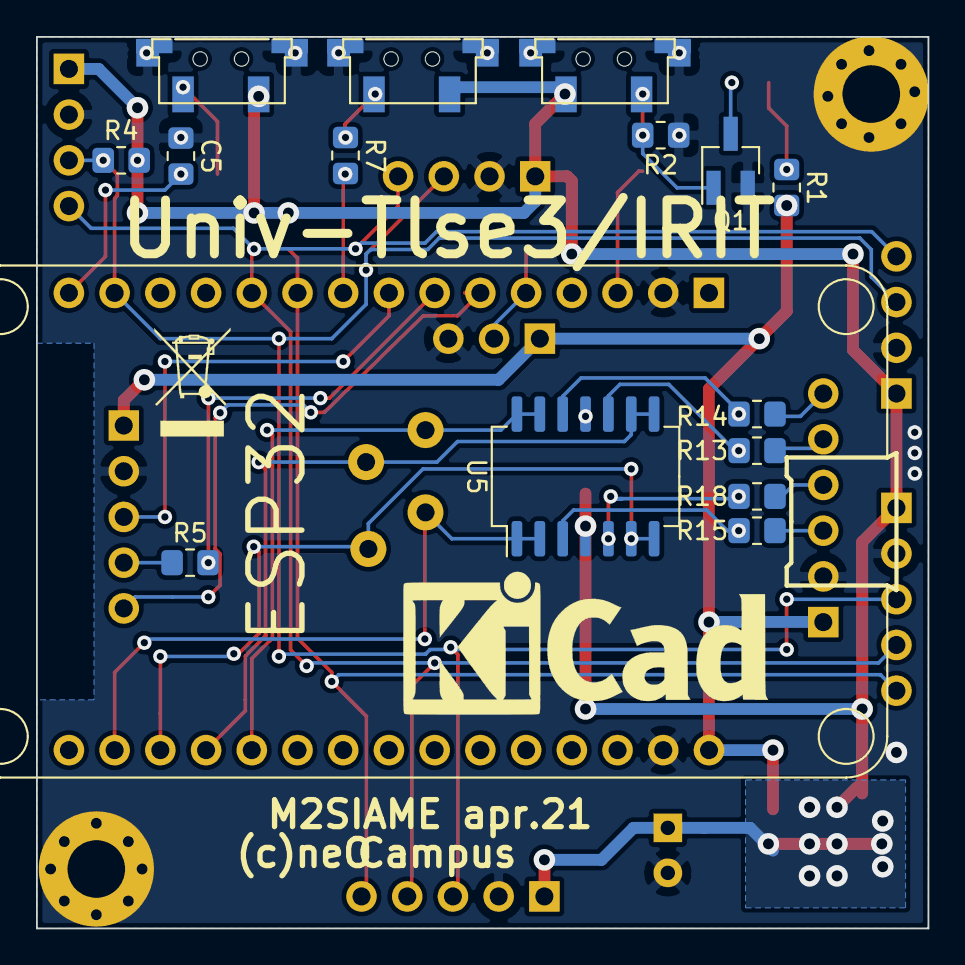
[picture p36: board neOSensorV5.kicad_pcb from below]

Board: 2 copper layers, 49.5 x 49.5 mm, 47 parts (16 on the bottom side), 31 nets.

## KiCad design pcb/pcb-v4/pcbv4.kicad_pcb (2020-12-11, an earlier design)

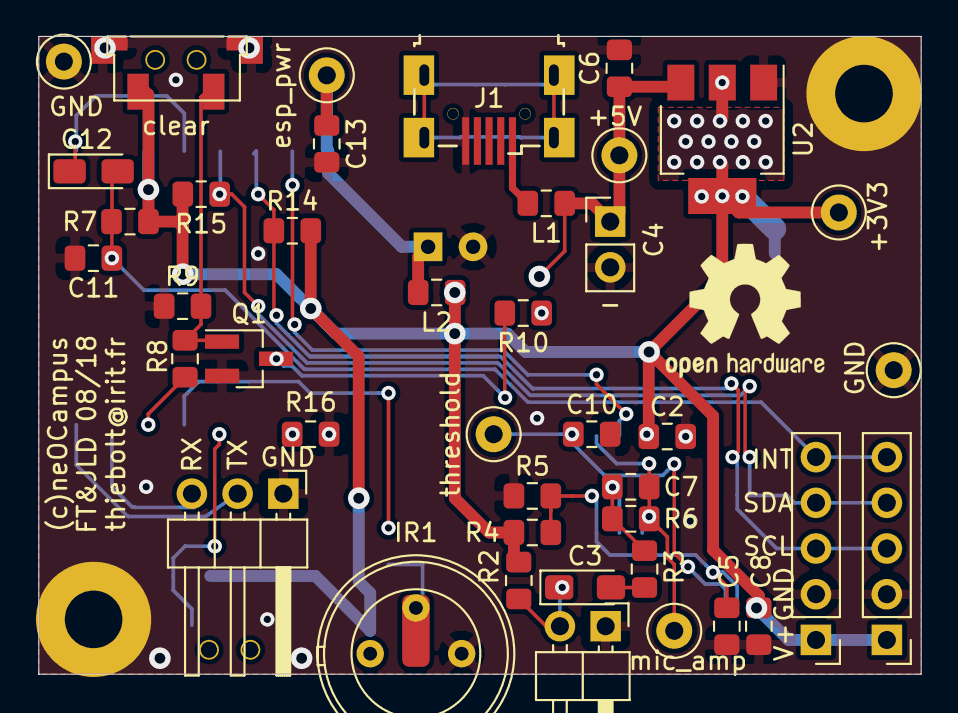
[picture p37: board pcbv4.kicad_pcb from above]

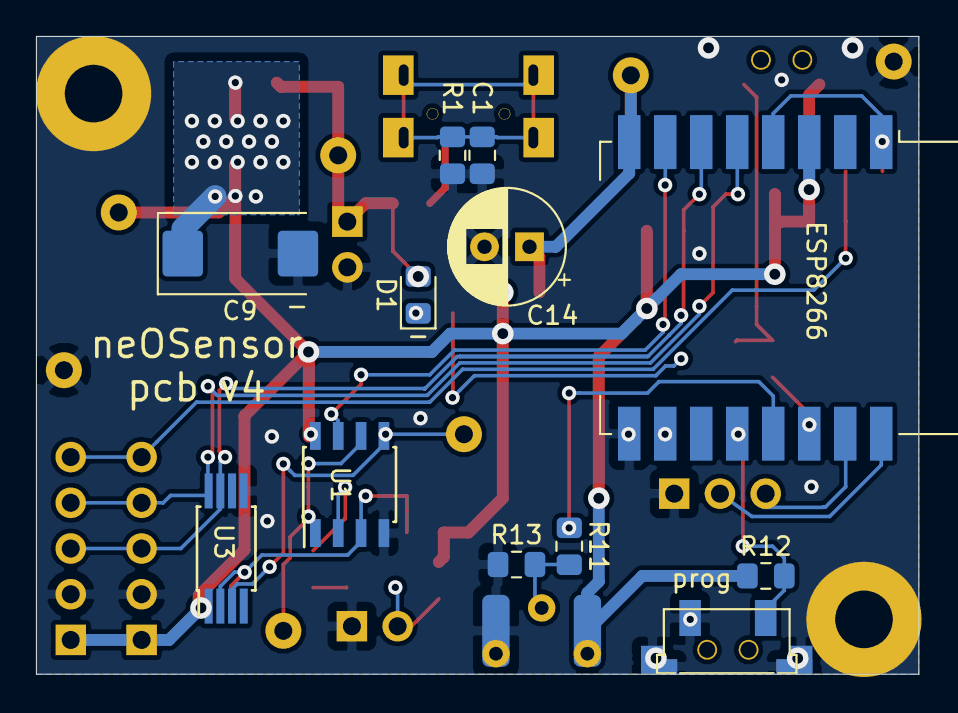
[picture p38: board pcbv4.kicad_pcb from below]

Board: 2 copper layers, 49.0 x 35.4 mm, 55 parts (12 on the bottom side), 27 nets.

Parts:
+3V3: +3v3; TestPoint_Loop_D2.50mm_Drill1.0mm
+5V: +5v; TestPoint_Loop_D2.50mm_Drill1.0mm
C1: 4n7; C_0805_2012Metric_Pad1.15x1.40mm_HandSolder
C2, C5, C8, C10, C11: 100n; C_0805_2012Metric_Pad1.15x1.40mm_HandSolder
C3: 1µ tantale; CP_EIA-3216-18_Kemet-A_Pad1.58x1.35mm_HandSolder
C4: 10µF (opt); PinHeader_1x02_P2.54mm_Vertical
C6, C13: 100nF; C_0805_2012Metric_Pad1.15x1.40mm_HandSolder
C7: 120p; C_0805_2012Metric_Pad1.15x1.40mm_HandSolder
C9: 220µF 6.3v; CP_EIA-7343-31_Kemet-D_Pad2.25x2.55mm_HandSolder
C12: 100nF to 1µF*; CP_EIA-3216-12_Kemet-S_Pad1.58x1.35mm_HandSolder
C14: 470µ 6.3v; CP_Radial_D6.3mm_P2.50mm
D1: Red; LED_0805_2012Metric_Pad1.15x1.40mm_HandSolder
ESP8266: ESP-12F-nospi
GND: GND; TestPoint_Loop_D2.50mm_Drill1.0mm
GND#2: GND; TestPoint_Loop_D2.50mm_Drill1.0mm
IR1: IRsensor; IRsensor_TH_and_smd
J1: USB_B_Micro; micro-usb-aliexpress
J2, J3: Conn_01x05; PinHeader_1x05_P2.54mm_Vertical
J4: Conn_01x03; PinHeader_1x03_P2.54mm_Horizontal
L1, L2: Ferrite 470R; R_0805_2012Metric_Pad1.15x1.40mm_HandSolder
MH1, MH2: 3.2mm for M3 screw; MountingHole_3.2mm_M3_Pad
MK1: Microphone; PinHeader_1x02_P2.54mm_Horizontal
Q1: 2N7002; SOT-23_Handsoldering
R1: 1M; R_0805_2012Metric_Pad1.15x1.40mm_HandSolder
R2: 2K; R_0805_2012Metric_Pad1.15x1.40mm_HandSolder
R3: 1K; R_0805_2012Metric_Pad1.15x1.40mm_HandSolder
R4, R5, R7, R12: 10K; R_0805_2012Metric_Pad1.15x1.40mm_HandSolder
R6: 100K; R_0805_2012Metric_Pad1.15x1.40mm_HandSolder
R8, R16: 470; R_0805_2012Metric_Pad1.15x1.40mm_HandSolder
R9, R13: 15K; R_0805_2012Metric_Pad1.15x1.40mm_HandSolder
R10: 68; R_0805_2012Metric_Pad1.15x1.40mm_HandSolder
R11: 330; R_0805_2012Metric_Pad1.15x1.40mm_HandSolder
R14, R15: 4K7; R_0805_2012Metric_Pad1.15x1.40mm_HandSolder
U1: AD8052; SOIC-8_3.9x4.9mm_P1.27mm
U2: AMS1117-3.3; SOT-223-3_TabPin2
U3: MCP47FEB21; TSSOP-8_4.4x3mm_P0.65mm_handsolder
clear: clear; G71Y_µsw_smd
esp_pwr: esp_pwr; TestPoint_Loop_D2.50mm_Drill1.0mm
mic_amp: MIC_AMP; TestPoint_Loop_D2.50mm_Drill1.0mm
prog: prog; G71Y_µsw_smd
threshold: Threshold; TestPoint_Loop_D2.50mm_Drill1.0mm

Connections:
+3V3: +3V3.1, C2.2, C8.2, C9.1, ESP8266.3, IR1.1, J2.1, J3.1, L2.2, R2.1, R4.1, R7.1, R12.1, R14.2, R15.2, U1.8, U2.2, U3.1, clear.1
+5V: +5V.1, C4.1, C6.1, D1.2, L1.1, U2.3
/GPIO0: ESP8266.18, R12.2, prog.1
/INT: C11.1, C12.2, J2.5, J3.5, R7.2
/IR: ESP8266.19, R11.2
/LED: ESP8266.20, R8.2
/NOISE: ESP8266.7, U1.7
/RST: C12.1, ESP8266.1, ESP8266.4
/RxD: ESP8266.21, J4.3
/SCL: ESP8266.6, J2.3, J3.3, R14.1, U3.7
/SDA: ESP8266.5, J2.4, J3.4, R15.1, U3.8
/TxD: ESP8266.22, J4.2
/esp_pwr: C13.1, C14.1, ESP8266.8, L2.1, esp_pwr.1
GND: C1.2, C2.1, C4.2, C5.2, C6.2, C8.1, C9.2, C10.2, C11.2, C13.2, C14.2, ESP8266.15, GND.1, GND#2.1, IR1.3, J1.5, J2.2, J3.2, J4.1, MH1.1, MH2.1, MK1.1, Q1.2, R1.2, R5.2, R9.1, R13.1, R16.1, U1.4, U2.1, U3.5, U3.6, clear.3, prog.2, prog.3
unnamed: C1.1, J1.6, R1.1
unnamed: C3.1, MK1.2, R2.2
unnamed: C3.2, R3.2
unnamed: C5.1, R4.2, R5.1, U1.3, U3.2
unnamed: C7.1, R6.1, U1.1, U1.6, mic_amp.1
unnamed: C7.2, R3.1, R6.2, U1.2
unnamed: C10.1, U1.5, U3.3, threshold.1
unnamed: D1.1, R10.1
unnamed: IR1.2, R11.1, R13.2
unnamed: J1.1, L1.2
unnamed: Q1.1, R8.1, R9.2, clear.2
unnamed: Q1.3, R10.2
unnamed: ESP8266.16, R16.2

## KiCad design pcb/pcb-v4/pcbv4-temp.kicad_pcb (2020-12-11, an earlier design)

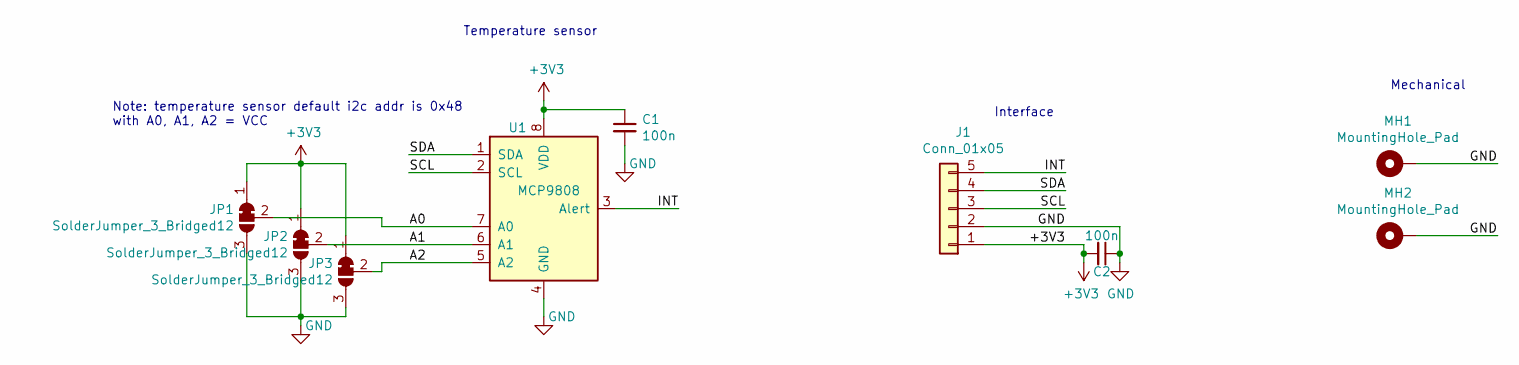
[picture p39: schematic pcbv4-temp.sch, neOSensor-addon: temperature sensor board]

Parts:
C1, C2: 100n; C_0805_2012Metric_Pad1.15x1.40mm_HandSolder
J1: Conn_01x05; PinHeader_1x05_P2.54mm_Vertical
JP1, JP2, JP3: SolderJumper_3_Bridged12; SolderJumper-3_P1.3mm_Bridged12_Pad1.0x1.5mm
MH1, MH2: MountingHole_Pad; MountingHole_3.2mm_M3_Pad
U1: MCP9808; MSOP-8_3x3mm_P0.65mm

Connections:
+3V3: C1.1, C2.2, J1.1, JP1.1 (A), JP2.1 (A), JP3.1 (A), U1.8 (VDD)
/A0: JP1.2 (C), U1.7 (A0)
/A1: JP2.2 (C), U1.6 (A1)
/A2: JP3.2 (C), U1.5 (A2)
/INT: J1.5, U1.3 (Alert)
/SCL: J1.3, U1.2 (SCL)
/SDA: J1.4, U1.1 (SDA)
GND: C1.2, C2.1, J1.2, JP1.3 (B), JP2.3 (B), JP3.3 (B), MH1.1, MH2.1, U1.4 (GND)

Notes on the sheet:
Temperature sensor
Interface
Note: temperature sensor default i2c addr is 0x48 with A0, A1, A2 = VCC
Mechanical

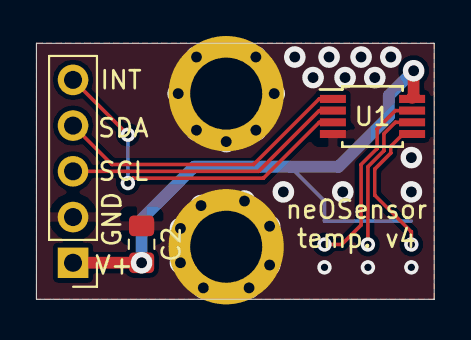
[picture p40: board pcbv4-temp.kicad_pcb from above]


Board: 2 copper layers, 22.1 x 14.2 mm, 9 parts (4 on the bottom side), 8 nets.

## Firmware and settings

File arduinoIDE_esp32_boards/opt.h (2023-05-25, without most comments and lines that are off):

#if !defined LWIP_HDR_OPT_H
#define LWIP_HDR_OPT_H
#include "lwipopts.h"
#include "lwip/debug.h"
#if !defined NO_SYS || defined __DOXYGEN__
#define NO_SYS                          0
#endif
#if !defined LWIP_TIMERS || defined __DOXYGEN__
#ifdef NO_SYS_NO_TIMERS
#define LWIP_TIMERS                     (!NO_SYS || (NO_SYS && !NO_SYS_NO_TIMERS))
#else
#define LWIP_TIMERS                     1
#endif
#endif
#if !defined LWIP_TIMERS_CUSTOM || defined __DOXYGEN__
#define LWIP_TIMERS_CUSTOM              0
#endif
#if !defined MEMCPY || defined __DOXYGEN__
#define MEMCPY(dst,src,len)             memcpy(dst,src,len)
#endif
#if !defined SMEMCPY || defined __DOXYGEN__
#define SMEMCPY(dst,src,len)            memcpy(dst,src,len)
#endif
#if !defined MEMMOVE || defined __DOXYGEN__
#define MEMMOVE(dst,src,len)            memmove(dst,src,len)
#endif
#if !defined LWIP_MPU_COMPATIBLE || defined __DOXYGEN__
#define LWIP_MPU_COMPATIBLE             0
#endif
#if !defined LWIP_TCPIP_CORE_LOCKING || defined __DOXYGEN__
#define LWIP_TCPIP_CORE_LOCKING         1
#endif
#if !defined LWIP_TCPIP_CORE_LOCKING_INPUT || defined __DOXYGEN__
#define LWIP_TCPIP_CORE_LOCKING_INPUT   0
#endif
#if !defined SYS_LIGHTWEIGHT_PROT || defined __DOXYGEN__
#define SYS_LIGHTWEIGHT_PROT            1
#endif
#if !defined LWIP_ASSERT_CORE_LOCKED || defined __DOXYGEN__
#define LWIP_ASSERT_CORE_LOCKED()
#endif
#if !defined LWIP_MARK_TCPIP_THREAD || defined __DOXYGEN__
#define LWIP_MARK_TCPIP_THREAD()
#endif
#if !defined MEM_LIBC_MALLOC || defined __DOXYGEN__
#define MEM_LIBC_MALLOC                 0
#endif
#if !defined MEMP_MEM_MALLOC || defined __DOXYGEN__
#define MEMP_MEM_MALLOC                 0
#endif
#if !defined MEMP_MEM_INIT || defined __DOXYGEN__
#define MEMP_MEM_INIT                   0
#endif
#if !defined MEM_ALIGNMENT || defined __DOXYGEN__
#define MEM_ALIGNMENT                   1
#endif
#if !defined MEM_SIZE || defined __DOXYGEN__
#define MEM_SIZE                        1600
#endif
#if !defined MEMP_OVERFLOW_CHECK || defined __DOXYGEN__
#define MEMP_OVERFLOW_CHECK             0
#endif
#if !defined MEMP_SANITY_CHECK || defined __DOXYGEN__
#define MEMP_SANITY_CHECK               0
#endif
#if !defined MEM_OVERFLOW_CHECK || defined __DOXYGEN__
#define MEM_OVERFLOW_CHECK              0
#endif
#if !defined MEM_SANITY_CHECK || defined __DOXYGEN__
#define MEM_SANITY_CHECK                0
#endif
#if !defined MEM_USE_POOLS || defined __DOXYGEN__
#define MEM_USE_POOLS                   0
#endif
#if !defined MEM_USE_POOLS_TRY_BIGGER_POOL || defined __DOXYGEN__
#define MEM_USE_POOLS_TRY_BIGGER_POOL   0
#endif
#if !defined MEMP_USE_CUSTOM_POOLS || defined __DOXYGEN__
#define MEMP_USE_CUSTOM_POOLS           0
#endif
#if !defined LWIP_ALLOW_MEM_FREE_FROM_OTHER_CONTEXT || defined __DOXYGEN__
#define LWIP_ALLOW_MEM_FREE_FROM_OTHER_CONTEXT 0
#endif
#if !defined MEMP_NUM_PBUF || defined __DOXYGEN__
#define MEMP_NUM_PBUF                   16
#endif
#if !defined MEMP_NUM_RAW_PCB || defined __DOXYGEN__
#define MEMP_NUM_RAW_PCB                4
#endif
#if !defined MEMP_NUM_UDP_PCB || defined __DOXYGEN__
#define MEMP_NUM_UDP_PCB                4
#endif
#if !defined MEMP_NUM_TCP_PCB || defined __DOXYGEN__
#define MEMP_NUM_TCP_PCB                5
#endif
#if !defined MEMP_NUM_TCP_PCB_LISTEN || defined __DOXYGEN__
#define MEMP_NUM_TCP_PCB_LISTEN         8
#endif
#if !defined MEMP_NUM_TCP_SEG || defined __DOXYGEN__
#define MEMP_NUM_TCP_SEG                16
#endif
#if !defined MEMP_NUM_ALTCP_PCB || defined __DOXYGEN__
#define MEMP_NUM_ALTCP_PCB              MEMP_NUM_TCP_PCB
#endif
#if !defined MEMP_NUM_REASSDATA || defined __DOXYGEN__
#define MEMP_NUM_REASSDATA              5
#endif
#if !defined MEMP_NUM_FRAG_PBUF || defined __DOXYGEN__
#define MEMP_NUM_FRAG_PBUF              15
#endif
#if !defined MEMP_NUM_ARP_QUEUE || defined __DOXYGEN__
#define MEMP_NUM_ARP_QUEUE              30
#endif
#if !defined MEMP_NUM_IGMP_GROUP || defined __DOXYGEN__
#define MEMP_NUM_IGMP_GROUP             8
#endif
#if ESP_LWIP
#define LWIP_NUM_SYS_TIMEOUT_INTERNAL   (LWIP_TCP + IP_REASSEMBLY + (LWIP_ARP + (ESP_GRATUITOUS_ARP ? 1 : 0)) + (ESP_LWIP_DHCP_FINE_TIMERS_ONDEMAND ? LWIP_DHCP : 2*LWIP_DHCP + (ESP_DHCPS_TIMER ? 1 : 0)) + LWIP_AUTOIP + LWIP_IGMP + (ESP_LWIP_DNS_TIMERS_ONDEMAND ? 0 : LWIP_DNS) + PPP_NUM_TIMEOUTS + (LWIP_IPV6 * (1 + LWIP_IPV6_REASS + LWIP_IPV6_MLD)))
#else
#define LWIP_NUM_SYS_TIMEOUT_INTERNAL   (LWIP_TCP + IP_REASSEMBLY + LWIP_ARP + (2*LWIP_DHCP) + LWIP_AUTOIP + LWIP_IGMP + LWIP_DNS + PPP_NUM_TIMEOUTS + (LWIP_IPV6 * (1 + LWIP_IPV6_REASS + LWIP_IPV6_MLD)))
#endif
#if !defined MEMP_NUM_SYS_TIMEOUT || defined __DOXYGEN__
#define MEMP_NUM_SYS_TIMEOUT            LWIP_NUM_SYS_TIMEOUT_INTERNAL
#endif
#if !defined MEMP_NUM_NETBUF || defined __DOXYGEN__
#define MEMP_NUM_NETBUF                 2
#endif
#if !defined MEMP_NUM_NETCONN || defined __DOXYGEN__
#define MEMP_NUM_NETCONN                4
#endif
#if !defined MEMP_NUM_SELECT_CB || defined __DOXYGEN__
#define MEMP_NUM_SELECT_CB              4
#endif
#if !defined MEMP_NUM_TCPIP_MSG_API || defined __DOXYGEN__
#define MEMP_NUM_TCPIP_MSG_API          8
#endif
#if !defined MEMP_NUM_TCPIP_MSG_INPKT || defined __DOXYGEN__
#define MEMP_NUM_TCPIP_MSG_INPKT        8
#endif
#if !defined MEMP_NUM_NETDB || defined __DOXYGEN__
#define MEMP_NUM_NETDB                  1
#endif
#if !defined MEMP_NUM_LOCALHOSTLIST || defined __DOXYGEN__
#define MEMP_NUM_LOCALHOSTLIST          1
#endif
#if !defined PBUF_POOL_SIZE || defined __DOXYGEN__
#define PBUF_POOL_SIZE                  16
#endif
#if !defined MEMP_NUM_API_MSG || defined __DOXYGEN__
#define MEMP_NUM_API_MSG                MEMP_NUM_TCPIP_MSG_API
#endif
#if !defined MEMP_NUM_DNS_API_MSG || defined __DOXYGEN__
#define MEMP_NUM_DNS_API_MSG            MEMP_NUM_TCPIP_MSG_API
#endif
#if !defined MEMP_NUM_SOCKET_SETGETSOCKOPT_DATA || defined __DOXYGEN__
#define MEMP_NUM_SOCKET_SETGETSOCKOPT_DATA MEMP_NUM_TCPIP_MSG_API
#endif
#if !defined MEMP_NUM_NETIFAPI_MSG || defined __DOXYGEN__
#define MEMP_NUM_NETIFAPI_MSG           MEMP_NUM_TCPIP_MSG_API
#endif
#if !defined LWIP_ARP || defined __DOXYGEN__
#define LWIP_ARP                        1
#endif
#if !defined ARP_TABLE_SIZE || defined __DOXYGEN__
#define ARP_TABLE_SIZE                  10
#endif
#if !defined ARP_MAXAGE || defined __DOXYGEN__
#define ARP_MAXAGE                      300
#endif
#if !defined ARP_QUEUEING || defined __DOXYGEN__
#define ARP_QUEUEING                    0
#endif
#if !defined ARP_QUEUE_LEN || defined __DOXYGEN__
#define ARP_QUEUE_LEN                   3
#endif
#if !defined ETHARP_SUPPORT_VLAN || defined __DOXYGEN__
#define ETHARP_SUPPORT_VLAN             0
#endif
#if !defined LWIP_ETHERNET || defined __DOXYGEN__
#define LWIP_ETHERNET                   LWIP_ARP
#endif
#if !defined ETH_PAD_SIZE || defined __DOXYGEN__
#define ETH_PAD_SIZE                    0
#endif
#if !defined ETHARP_SUPPORT_STATIC_ENTRIES || defined __DOXYGEN__
#define ETHARP_SUPPORT_STATIC_ENTRIES   0
#endif
#if !defined ETHARP_TABLE_MATCH_NETIF || defined __DOXYGEN__
#define ETHARP_TABLE_MATCH_NETIF        !LWIP_SINGLE_NETIF
#endif
#if !defined LWIP_IPV4 || defined __DOXYGEN__
#define LWIP_IPV4                       1
#endif
#if !defined IP_FORWARD || defined __DOXYGEN__
#define IP_FORWARD                      0
#endif
#if !defined IP_REASSEMBLY || defined __DOXYGEN__
#define IP_REASSEMBLY                   1
#endif
#if !defined IP_FRAG || defined __DOXYGEN__
#define IP_FRAG                         1
#endif
#if !LWIP_IPV4
#undef IP_FORWARD
#define IP_FORWARD                      0
#undef IP_REASSEMBLY
#define IP_REASSEMBLY                   0
#undef IP_FRAG
#define IP_FRAG                         0
#endif
#if !defined IP_NAPT || defined __DOXYGEN__
#define IP_NAPT                      0
#endif
#if !defined IP_OPTIONS_ALLOWED || defined __DOXYGEN__
#define IP_OPTIONS_ALLOWED              1
#endif
#if !defined IP_REASS_MAXAGE || defined __DOXYGEN__
#define IP_REASS_MAXAGE                 15
#endif
#if !defined IP_REASS_MAX_PBUFS || defined __DOXYGEN__
#define IP_REASS_MAX_PBUFS              10
#endif
#if !defined IP_DEFAULT_TTL || defined __DOXYGEN__
#define IP_DEFAULT_TTL                  255
#endif
#if !defined IP_SOF_BROADCAST || defined __DOXYGEN__
#define IP_SOF_BROADCAST                0
#endif
#if !defined IP_SOF_BROADCAST_RECV || defined __DOXYGEN__
#define IP_SOF_BROADCAST_RECV           0
#endif
#if !defined IP_FORWARD_ALLOW_TX_ON_RX_NETIF || defined __DOXYGEN__
#define IP_FORWARD_ALLOW_TX_ON_RX_NETIF 0
#endif
#if !defined LWIP_ICMP || defined __DOXYGEN__
#define LWIP_ICMP                       1
#endif
#if !defined ICMP_TTL || defined __DOXYGEN__
#define ICMP_TTL                        IP_DEFAULT_TTL
#endif
#if !defined LWIP_BROADCAST_PING || defined __DOXYGEN__
#define LWIP_BROADCAST_PING             0
#endif
#if !defined LWIP_MULTICAST_PING || defined __DOXYGEN__
#define LWIP_MULTICAST_PING             0
#endif
#if !defined LWIP_RAW || defined __DOXYGEN__
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

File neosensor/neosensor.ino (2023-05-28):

/*
 * neOCampus operation
 * 
 * neOSensor firmware for various ESP8266 and ESP32 based boards:
 * - neoSensor boards based on either esp32 or esp8266
 * - neOSensor-Airquality board based on esp32
 * 
 * (c) F.Thiebolt / neOCampus operation - Université Toulouse 3
 * 
 * ---
 * NOTES:
 * - you need to 'deploy' our boards definitions (run the deploy.sh script)
 * - select your board from the Arduino IDE boards menu (located end of list)
 * - a compilation flag tells which bord it is (i.e NEOSENSOR_AIRQUALITY)
 * - as of aug.20, [ESP32] CONFIG_LWIP_MAX_ACTIVE_TCP=16
 * 
 * ---
 * KNOWN ISSUES:
 * - ONLY ONE SHT3x per neOSensor supported.
 *    This stems from the fact that the SHT3x driver features static variables 
 *    shared across all instances.
 *
 * ---
 * TODO:
 * - loadSensoConfig --> avoid data duplication, implement an iterator
 * - remove DISABLE_SSL compilation flag
 * ----------------------------------------------------------------------------- */



/* #############################################################################
 * ###                                                                       ###
 * ###             ARDUINO'S IDE BOARD HARDWARE SELECTION                    ###
 * ###                                                                       ###
 * 
 *      Proper board will be selected according to the selection you made 
 *      within the Arduino board selector
 * 
 * >>>     Don't forget to update BOARD_FWREV from your 'board/neOXxx.h'     <<<
 * 
 * ############################################################################# */



/*
 * Includes
 */
#ifdef ESP8266
  /* specify timezone; daylight will automatically follow :) */
  #include <TZ.h>
#endif

#include <Arduino.h>
#include <Wire.h>
#include <Ticker.h>
#if defined(ESP8266)
  #include <ESP8266WiFi.h>
#elif defined(ESP32)
  #include <WiFi.h>
  #include <esp_wifi.h>
#endif
#include <lwipopts.h>                     // for ESP32 max tcp connections CONFIG_LWIP_MAX_ACTIVE_TCP

/* As of esp8266 arduino lib >=2.4.0, time is managed via local or sntp along with TZ support :) */ 
#include <time.h>                         // time() ctime()
#include <sntp.h>
#ifdef ESP8266
  #include <coredecls.h>                  // settimeofday_cb(), tune_timeshift64()
#endif

/*
 * ESP8266 advanced ops
 */
#if defined ESP8266
  extern "C" {
    #include "user_interface.h"           // wifi_station_dhcpc_start, ...
  }
#endif /* ESP8266 */

/*
 * ESP32 advanced ops:
 * - enhanced ADC (calibration)
 */
#if defined(ESP32) && !defined(DISABLE_ADC_CAL)
  #include <esp_adc_cal.h>
  #define DEFL_ESP32_ADC_VREF       1100  // default 1100mv thay will get used ONLY if efuse vref is not set (i.e uncalibrated esp32 ---before Q1-18)
  esp_adc_cal_value_t esp_adc_cal_src       = (esp_adc_cal_value_t)(-1);
  esp_adc_cal_characteristics_t *adc_chars  = new esp_adc_cal_characteristics_t;
#endif /* ESP32 adcanced ADC */



/* neOCampus related includes */
#include "neocampus.h"

#include "neocampus_debug.h"
#include "neocampus_utils.h"
#include "neocampus_i2c.h"
#include "sensocampus.h"
#include "neocampus_OTA.h"
//#include "neocampus_comm.h"               // future MQTT(s) comm module: a single MQTTclient shared with multiple subscribers featuring different callbacks

/* neOCampus modules
 * !! WARNING !!
 * Each module makes use of a TCP connection to the neOCampus server (MQTT link)
 * check that there's enough TCP links available !!
 */
#include "device.h"
#include "temperature.h"
#include "humidity.h"
#include "luminosity.h"
#include "noise.h"
#include "neoclock.h"
#include "airquality.h"
#include "digital.h"
#include "display.h"

// modules management
#include "modulesMgt.h"

// WiFi parameters management
#include "wifiParametersMgt.h"



/*
 * Definitions
*/

// Debug related definitions
#define SERIAL_BAUDRATE   115200
#ifdef ESP8266
  #if (LOG_LEVEL > 0) || defined(DEBUG_WIFI_MANAGER)
    #include <SoftwareSerial.h>
  #endif
#endif /* ESP8266 */

// sensOCampus related definitions
#define SENSO_MAX_RETRIES         5   // maximum number of sensOCampus configuration retrieval retries

// Time related definitions
#ifdef ESP8266
  #define MYTZ                    TZ_Europe_Paris
#elif defined(ESP32)
  //#define MYTZ                    "Europe/Paris" [nov.21] why is it not working ?!?!
  #define MYTZ                    "CET-1CEST,M3.5.0/2,M10.5.0/3"
  //const long  gmtOffset_sec = 3600; [nov.21] daylight changing does not work
  //const int   daylightOffset_sec = 3600;
#endif
#define NTP_DEFAULT_SERVER1       "pool.ntp.org"      // DNS location aware
//#define NTP_DEFAULT_SERVER1       "time.nist.gov"     // DNS location aware
//#define NTP_DEFAULT_SERVER2       "0.fr.pool.ntp.org" // DNS location aware
#define NTP_DEFAULT_SERVER2       "ntp.irit.fr"       // UT3-IRIT specific
#define NTP_DEFAULT_SERVER3       "ntp.univ-tlse3.fr" // UT3 specific


/*
 * various led mods to express status of neOSensor
 * device while in setup()
 */
#ifdef ESP8266
  // since 3.X sdk, default range of analogWrite is now 255 while it used to be 1023
  #define ESP8266_PWMRANGE    1023
#endif
typedef enum {
  WIFI,
  DISABLE
} enum_ledmode_t;


/*
 * Global variables
 */
bool _need2reboot = false;              // flag to tell a reboot is requested

// WiFi parameters management statically allocated instance
wifiParametersMgt wifiParameters = wifiParametersMgt();

// sensOCampus statically allocated instance with link to global wifi parameters (to check against sandbox mode)
senso sensocampus = senso( &wifiParameters );

// modules management statically allocated instance
modulesMgt modulesList = modulesMgt();

// device statically allocated instance
device deviceModule = device();

// temperature class module
temperature *temperatureModule      = nullptr;

// humidity class module
humidity *humidityModule            = nullptr;

// luminosity class module
luminosity *luminosityModule        = nullptr;

// noise class module
noise *noiseModule                  = nullptr;
// noise module ISR :(
void IRAM_ATTR noiseDetectISR() {             /* https://community.particle.io/t/cpp-attachinterrupt-to-class-function-help-solved/5147/2 */
  if( noiseModule ) noiseModule->noiseDetectISR();
}

// neoclock class module
neoclock *clockModule               = nullptr;

// airquality class module
airquality *airqualityModule        = nullptr;

// digital class module
digital *digitalModule              = nullptr;

// display class module
display *displayModule              = nullptr;


// time server related
bool cbtime_set = false;
bool _cbtime_call = false;          // used to display things about time sync
time_t cbtime_cur, cbtime_prev;     // time set in callback


/*
 * [aug.21] shared JSON document to allow modules to exchange data.
 * ... mainly used by display module ;)
 */
#define MODULES_SHARED_JSON_SIZE  512
//StaticJsonDocument<MODULES_SHARED_JSON_SIZE> sharedRoot;    // stack allocation
DynamicJsonDocument sharedRoot(MODULES_SHARED_JSON_SIZE);   // heap allocation


// --- Functions ---------------------------------------------------------------
void setupSerial( void ) {
#ifdef SERIAL_BAUDRATE
  delay(3000);  // time for USB serial link to come up anew
  Serial.begin(SERIAL_BAUDRATE); // Start serial for output

  // Arduino libs v2.4.1, to enable printf and debug messages output
  Serial.setDebugOutput( true );
  
  char tmp[96];
  snprintf(tmp,sizeof(tmp),"\n\n\n\n# %s firmware rev %d for neOCampus is starting ... ",getBoardName(),getFirmwareRev());
  log_info(tmp);
  log_info(F("\n#\tMac address is ")); log_info(getMacAddress());
  log_info(F("\n#\tlog level is ")); log_info(LOG_LEVEL,DEC);
  log_info(F("\n"));
  log_flush();
#endif
#ifndef DEBUG_WIFI_MANAGER
  wifiManager.setDebugOutput(false);
#endif
}



// ---
// Setup system led (mostly led2 on ESP8266) i.e blue led on ESP12E/F near antenna
// we then use serial link1 used to either core debugging or just to blink led2
void setupSysLed( void ) {
#if defined(ESP8266) && defined(SYS_LED)
  if( SYS_LED != INVALID_GPIO ) {
    // ESP8266's GPIO2 is tied to Serial1's TX
    Serial1.begin( 115200, (SerialConfig)SERIAL_8N1, (SerialMode)UART_TX_ONLY, SYS_LED);
  
    // Arduino libs v2.4.1, to enable printf and debug messages output
    // Serial1.setDebugOutput( true ); // default
    return;
  }
#elif defined(ESP32) && defined(SYS_LED)
  if( SYS_LED != INVALID_GPIO ) {  
    pinMode(SYS_LED, OUTPUT);
    return;
  }
#endif
  log_info(F("\nNO SYS_LED defined.")); log_flush();
}


// ---
// clear Sensors WiFi, EEPROM, config files (SPIFFS) ...
// ... called upon clear SWITCH button activated at startup
void clearSensor( void ) {
  log_debug(F("\n[CLEAR] starting CLEAR procedure ..."));

  // clear WiFi credentials
  WiFi.disconnect();

  // clear JSON config files (SPIFFS)
  formatSPIFFS();
}


// ---
// I2C setup pins and frequency
bool setupI2C( void ) {

  if( _need2reboot ) return false;

  // if not defined SDA and SCL ... give up
  if( SDA==INVALID_GPIO or SCL==INVALID_GPIO ) {
    log_info(F("\nI2C bus disabled.")); log_flush();
    return false;
  }
  
  log_info(F("\n[i2c] start setup ..."));
  Wire.begin(SDA,SCL);
  #ifdef I2C_FREQ
    log_debug(F("\nI2C frequency set to "));log_debug(I2C_FREQ/1000,DEC); log_debug("kHz"); log_flush();
    Wire.setClock(I2C_FREQ);
  #else
    log_debug(F("\nI2C frequency set to default 100kHz")); log_flush();
  #endif
  return true;
}


// ---
// Blink system led
inline void blinkSysLed( void ) {
#ifdef ESP8266
  /* ESP8266's onboard blue led (GPIO2) is tied to Serial1:
    * send zero(s) to blink the led
    */
  byte _msg[] = {0x00, 0x00, 0x00, 0x00 };
  Serial1.write(_msg, sizeof(_msg));Serial1.flush();
#elif defined(ESP32)
  /* ESP32 does not feature the blue led like in ESP12E/F modules
   * ==> SYS_LED not defined ==> use LED (if defined and if no NoiseModule)
   */
  uint8_t _led = SYS_LED;
  if( _led==INVALID_GPIO && LED!=INVALID_GPIO && noiseModule==nullptr ) _led = LED;
  if( _led != INVALID_GPIO ) {
    digitalWrite( _led, HIGH);
    delay(50);
    digitalWrite( _led, LOW);
  }
#endif
}


// ---
// process end of main loop: specific functions executed every seconds
void endLoop( void ) {
  static unsigned long _lastCheck = 0;    // elapsed ms since last check

#if 0
  // ONY FOR DEBUGGING
  static unsigned long _lastJSONdisplay = 0;    // elapsed ms since last displying shared JSON
  // 90s second elapsed ?
  if( ((millis() - _lastJSONdisplay) >= (unsigned long)90*1000UL) == true ) {
    _lastJSONdisplay = millis();
    log_debug(F("\nGlobal sharedJSON:\n")); log_flush();
    serializeJsonPretty( sharedRoot, Serial );
  }
#endif /* 0 */

  // check if a reboot has been requested ...
  if( _need2reboot ) {
    log_info(F("\n[REBOOT] a reboot has been asked ..."));log_flush();
    #ifndef DISABLE_MODULES
    modulesList.stopAll();
    #endif
    neOSensor_reboot();
    delay(5000); // to avoid an infinite loop
  }

  // a second elapsed ?
  if( ((millis() - _lastCheck) >= (unsigned long)1000UL) == true ) {
    _lastCheck = millis();

    /* blink SYS_LED */
    blinkSysLed();

    // check Heap available
    if( ESP.getFreeHeap() < 4096 ) {
      log_error(F("\n[SYS] CRTICAL free heap very low!!!")); log_flush();
    }

    // display NTP servers used for time sync
    if( _cbtime_call ) {
      _cbtime_call = false;

      //log_debug(F("\n[NTP_sync] IP_ADDR_ANY = "));log_debug(ipaddr_ntoa(&ip_addr_any));log_flush();

      // list active ntp servers
      for( uint8_t i=0; i<SNTP_MAX_SERVERS; i++ ) {
        const ip_addr_t* p_cur = sntp_getserver(i);
        if( ip_addr_cmp(p_cur, IP_ADDR_ANY) ) continue;
        log_debug(F("\n[NTP_sync] IPaddr = "));log_debug(ipaddr_ntoa(p_cur));log_flush();
      }
    }

    // serial link activity marker ...
    log_debug(F("."));
  }
}


// --- LED MODES while in setup()
// ledWiFiMode, i.e fade-in / fade-out constantly
// input is either the led_pin (esp8266)
// or the channel_id (esp32)
void _ledWiFiMode( uint8_t id ) {

#ifdef ESP8266

  const uint8_t _val_steps = 50;
  static int16_t _val=0;
  
  if( _val < ESP8266_PWMRANGE ) _val+=_val_steps;
  else _val=-ESP8266_PWMRANGE;

  analogWrite( id, (abs(_val)<ESP8266_PWMRANGE) ? abs(_val) : ESP8266_PWMRANGE );

#elif defined(ESP32)
  /* Ok, we'll get called every 50ms ... 
   *  we want fade_in across 1s and fade_out across another 1s
   *  ==> 20 steps for each fade_
   *  Channel resolution being 10bits ==> 1024 / 20 = #50
   *  ... thus each steo will increase/decrese duty by this step
   */
  const uint8_t _val_steps = (pow(2,LED_RESOLUTION)-1) / 20;
  static int32_t _duty = 0;

  if( _duty < pow(2,LED_RESOLUTION) ) _duty+=_val_steps;
  else _duty = -pow(2,LED_RESOLUTION);

  ledcWrite( id, (abs(_duty)<(pow(2,LED_RESOLUTION)-1)) ? abs(_duty) : pow(2,LED_RESOLUTION)-1 );
#endif
}


// various led modes to express neOSensor status while in setup()
void setupLed( uint8_t led, enum_ledmode_t led_mode ) {

  if( led == INVALID_GPIO ) return;

  log_debug(F("\n[setupLed] starting to setup led '"));log_debug(led,DEC);
  log_debug(F("' with mode: "));log_debug(led_mode,DEC);
  log_flush();
  
  static Ticker timer_led;

  switch( led_mode ) {
    case WIFI:
      // set led to show we're waiting for WiFi connect
#ifdef ESP8266
      pinMode(led,OUTPUT);
      analogWriteRange(ESP8266_PWMRANGE);
      timer_led.attach_ms(50, _ledWiFiMode, led);
#elif defined(ESP32)
      ledcSetup(LED_CHANNEL, LED_BASE_FREQ, LED_RESOLUTION);
      ledcAttachPin( led, LED_CHANNEL);
      timer_led.attach_ms(50, _ledWiFiMode, LED_CHANNEL);
#endif
      break;

    case DISABLE:
      // switch back to INPUT mode (default after reset)
      timer_led.detach();
#ifdef ESP8266
      analogWrite( led, 0 );  // [Dec.17] workaround for resilient analog value written to led
#elif defined(ESP32)
      ledcDetachPin( led );
#endif
      pinMode(led,INPUT);
      break;

    default:
      log_error(F("\n[setupLed] unknwown led_mode ?!?!"));
  }

  return;
}


// ---
/* sync ntp callback:
 *  This function gets called whenever a NTP sync occurs
 */
#ifdef ESP32
void _syncNTP_cb(struct timeval *tv) {
  // tv arg is time from NTP server
  syncNTP_cb();
}
#endif
void syncNTP_cb( void ) {
  char _tmpbuf[64];
  struct tm *_tm;

  /* WARNING
   *  - gettimeofday --> TZ settings does not apply
   *  - time() while incorrect will get masked by localtime behaviour :s
   */
   
  // retrieve when time sync occured
  // gettimeofday( &cbtime_cur, NULL ); // WARNING: timezone does not apply ... :(
  // log_debug(F("\n[NTP] time sync occured ")); log_debug( ctime(&cbtime_cur.tv_sec) );
  time( &cbtime_cur );
  _tm = localtime( &cbtime_cur );   // Weird part ... localtime function *corrects* time to match timezone ... :s

  
  log_info(F("\n[NTP] sync CALLBACK ... ")); log_flush();

  /* Note: while in this callback, the ntp server
   *  is not yet written in the list of NTP servers!
  */

  // display time synchro message
  strftime( _tmpbuf, sizeof(_tmpbuf), "%Y-%m-%d %H:%M:%S %z", _tm);
  log_debug(F("\n[NTP] time sync occured ")); log_debug(_tmpbuf);

  // first call ?
  if( not cbtime_set ) {
    cbtime_set = true;
  }
  else {
    int16_t _sync_diff = cbtime_cur - ( cbtime_prev + (SNTP_UPDATE_DELAY/1000) ); // seconds
    if( abs(_sync_diff) <= 2 ) {
      log_info(F(" local clock well syncronized :)"));
    }
    else if( abs(_sync_diff) <= 60 ) {
      log_warning(F(" local clock shift(seconds)= "));log_info(_sync_diff,DEC);
    }
    else {
      log_debug(F(" local clock shift > 60s ... probably a WiFi resync ..."));
    }
  }
  log_flush();

  cbtime_prev = cbtime_cur;

  // callback called
  _cbtime_call = true;
}


// ---
// NTP setup
bool setupNTP( void ) {
  
  if( _need2reboot ) return false;

  log_debug(F("\n[NTP] start setup of (S)NTP ..."));

#ifdef ESP8266
  // register ntp sync callback
  settimeofday_cb( syncNTP_cb );
#elif ESP32
  // register ntp sync callback
  sntp_set_time_sync_notification_cb( _syncNTP_cb );
#endif    
  // [may.23] esp32/8266 unified API
  configTzTime( MYTZ, NTP_DEFAULT_SERVER1, NTP_DEFAULT_SERVER2, NTP_DEFAULT_SERVER3 );

  log_flush();
  // the end ...
  return true;
}


// ---
// process WiFi Parameters options
void processWIFIparameters( wifiParametersMgt *wp=nullptr ) {
  
  if( !wp ) return;

  log_debug(F("\n[wifiParams] start to process options ... ")); log_flush();

  //
  // check for ERASE ALL OPTION
  if( wp->isEnabledEraseALL() ) {
    log_info(F("\n[wifiParams] a WHOLE ERASE has been requested ...")); log_flush();
    clearSensor();
    log_debug(F("\n\t... and asking for reboot ..."));
    delay(250);
    _need2reboot = true;  // set flag for reboot
    // and no need to go further ...
    return;
  }

  //
  // TM1637 display
  if( wp->isEnabled7segTM1637() and !clockModule ) {
    log_info(F("\n[wifiParams] start 7 segments neoclock (TM1637 driven) ...")); log_flush();
    
    // allocate display with TM1637 7 segment driver
    clockModule = new neoclock();
    clockModule->add_display( NEOCLOCK_TM1637 );    
  }
  else if( !wp->isEnabled7segTM1637() and clockModule ) {
    log_info(F("\n[wifiParams] removing 7 segments neoclock (TM1637 driven) ...")); log_flush();

    // stop and de-allocate object
    clockModule->stop();
    free( clockModule );
    clockModule = nullptr;
  }
 
  //
  // PIR sensor
  if( wp->isEnabledPIR() and !digitalModule ) {
    log_info(F("\n[wifiParams] start PIR sensor ...")); log_flush();
    
    // allocate digital module
    digitalModule = new digital();
    digitalModule->add_gpio( "IRsensor", PIR_SENSOR, digitalInputType_t::presence, digitalFrontDetect_t::rising, 60 );  // 60s cooldown
  }


  /*
   * Add processing for additional options here !
   */
}


// ---
// show WiFi protocols in use
void display_wifi_protocol( void ) {

  uint8_t cur_protocols;
  int _err;
#ifdef ESP32
  _err = esp_wifi_get_protocol(WIFI_IF_STA, &cur_protocols);
  if( _err != ESP_OK ) {
    log_error(F("\n[WiFiProtocol] Could not get protocol!"));
    return;
  }
#elif defined (ESP8266)
  cur_protocols = (uint8_t)WiFi.getPhyMode();
#endif

  log_debug(F("\n# WIFI protocols = 0x"));log_debug(cur_protocols,HEX);log_flush();
#ifdef ESP32
  if( cur_protocols & WIFI_PROTOCOL_11N ) {
    log_debug(F("\n\tWiFi_Protocol_11n"));
  }
  if( cur_protocols & WIFI_PROTOCOL_11G ) {
    log_debug(F("\n\tWiFi_Protocol_11g"));
  }
  if( cur_protocols & WIFI_PROTOCOL_11B ) {
    log_debug(F("\n\tWiFi_Protocol_11b"));
  }
#elif defined (ESP8266)
  if( cur_protocols==WIFI_PHY_MODE_11N ) {
    log_debug(F("\n\tWiFi_Protocol_11n"));
  }
  else if( cur_protocols==WIFI_PHY_MODE_11G ) {
    log_debug(F("\n\tWiFi_Protocol_11g"));
  }
  else if( cur_protocols==WIFI_PHY_MODE_11B ) {
    log_debug(F("\n\tWiFi_Protocol_11b"));
  }
#endif
}


// ---
// earlySetup: called at the very begining of setup()
void earlySetup( void ) {

  // note: no log_xxx msg since they will get defined later
  // log_info(F("\n[Early] disable autoConnect and clear saved IP ...")); log_flush();

  /* [jan.23] due to numerous DHCP issues, and following issue https://github.com/esp8266/Arduino/issues/8299
   *  we decided to set WiFi physical mode explicitly
   *  BEWARE IT IS PERSISTENT across reboot, flash ...
   */
#ifdef FORCE_WIFI_PROTOCOL
  #warning "WiFi protocol enforcement is active !!"
  #if defined(ESP8266)
    //WiFi.setPhyMode(WIFI_PHY_MODE_11B);   // [jan.23] 11B or 11G SOLVED OUR DHCP issue !!!
    WiFi.setPhyMode(WIFI_PHY_MODE_11G);   // [may.23] 11B or 11G SOLVED OUR DHCP issue --> hope 11G allows 11B too
  #elif defined(ESP32)
    // set PERSISTANT mode for station
    WiFi.mode(WIFI_STA);
    //esp_wifi_set_protocol(WIFI_IF_STA, WIFI_PROTOCOL_11B);
    esp_wifi_set_protocol(WIFI_IF_STA, WIFI_PROTOCOL_11B|WIFI_PROTOCOL_11G);
    //esp_wifi_config_11b_rate(WIFI_IF_STA,true); // to suppress 802.11B
  #endif
#endif /* FORCE_WIFI_PROTOCOL */

  // WiFi.disconnect(true); // to erase default credentials
  WiFi.setAutoReconnect(false);

  // Disable sleep modes
#ifdef ESP8266
  WiFi.setSleepMode(WIFI_NONE_SLEEP);
#elif defined(ESP32)
  esp_sleep_pd_config(ESP_PD_DOMAIN_MAX,ESP_PD_OPTION_ON);
#endif

#if defined(ESP32) && !defined(DISABLE_ADC_CAL)
  // retrieve esp32 adc calibration
  adc1_config_width( ADC_RESOLUTION );
  // adc1_config_channel_atten(ADC1_CHANNEL_5,ADC_ATTEN_DB_11); sensor dependent !
  esp_adc_cal_src = 
           esp_adc_cal_characterize(ADC_UNIT_1, ADC_ATTEN_DB_11, ADC_RESOLUTION, DEFL_ESP32_ADC_VREF, adc_chars);
#endif /* ESP32 advanced ADC */
}


// ---
// lateSetup: called at the very end of setup()
void lateSetup( void ) {

  if( _need2reboot ) {
    log_warning(F("\nA reboot has been asked while in setup() ... probably a faulty WiFi connect ...")); log_flush();
    delay(3000);
    #ifndef DISABLE_MODULES
    modulesList.stopAll();
    #endif /* DISABLE_MODULES */
    neOSensor_reboot();
    delay(5000); // to avoid an infinite loop
  }
  
  char tmp[64];
  snprintf(tmp,sizeof(tmp),"\n\n\n#\n# %s firmware rev %d for neOCampus started :)",getBoardName(),getFirmwareRev());
  log_info(tmp);

  if( not cbtime_set ) {
    log_warning(F("\n#\t TIME NOT (YET) SYNCED !!"));
  }
  else {
    log_info(F("\n# current time is ")); log_info(getCurTime());
  }

  WiFi.setAutoReconnect(true);

  display_wifi_protocol();
  
#if ESP32
  // switch back POWER MODES to auto
  if( esp_sleep_pd_config(ESP_PD_DOMAIN_MAX,ESP_PD_OPTION_AUTO) != ESP_OK ) {
    log_warning(F("\nerror while restoring ESP32 power modes ?!?! ... continuing")); log_flush();
  }
#endif /* ESP32 */
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
void loop() {

  /*
   * Process device, module sensors ...
   */
  modulesList.processAll();


  /* 
   * end of main loop
   */
  // call endLoop system management level
  endLoop();
  
  // waiting a bit
  delay( MAIN_LOOP_DELAY );
}

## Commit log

2020-07-09 dual_client_class_test : issues while trying to make a base_class constructor initializing the on_message() function by a void* parameter
    [dual_client_class_test.ino]
2020-07-16 dual_client_test in progress: can fetch from SPIFFS and default login to the MQTT broker. on_message not working yet...
    [dual_client_class_test.ino, esp32_memory.cpp, get_config_JSON_SPIFFS_test.ino]
2020-07-24 runtime error was a damn typo in a snprintf call...
    [neosensor.ino]
2020-07-25 base_class is meant to be made from scratch again, current implementation isnt satisfying enough. Started work on a centralised architecture around the neoscheduler class: users .ino file will only h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
2020-07-27 issue : SPIFFS refuses to boot up.
    [neosensor.ino]
2020-07-27 SPIFFS boots up on laptop however fail to initialize if i compile and upload from my home machine.
    [neosensor.ino]
2020-07-28 morning workload: moving to littleFS [bug-fixing]
    [esp32_memory.cpp]
2020-07-30 implementing https class [why all the supposed https tests broke?]
    [conn_test.ino]
2020-08-05 wm_store_credentials : fixed issue with JsonDocument no writing into flash.
    [wm_store_credentials.ino]
2020-08-14 now able to filter a JSON configuration for a specific module
2020-08-24 added regular neOSensor board. sensOCampus JSON config is working.
2020-08-26 start to add support for ESP32 ADC calibration
2020-08-27 strating to enable advanced adc ops on esp32
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2020-09-08 switched esp8266 from QIO to DIO flash mode
2020-09-10 corrected wront unitID for deviceModule
2020-11-02 corrected force float values for temperatire and airquality
2020-11-09 use LED when SYS_LED not available
2020-11-10 start of SSD1306 display driver
2021-01-04 update repo structure for future pcb-v5
    [neOSensorV4_panel-B.Cu.gbl, neOSensorV4_panel-B.Mask.gbs, neOSensorV4_panel-B.SilkS.gbo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]
2021-02-03 started pcb v5
    [neOSensorV5.kicad_pcb, neOSensorV5.sch]
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2021-02-04 update pcb v5
    [neOSensorV5.sch]
2021-02-05 update neOSensor V5
    [neOSensorV5.sch]
2021-02-07 added analog inputs to pcb v5
    [neOSensorV5.sch]
2021-02-10 added nodes labels and minor corrections to pcb v5
    [neOSensorV5.kicad_pcb, neOSensorV5.sch]
2021-02-10 panelized PCB V5 ready for manufacturing
    [neOSensorv5_panelized-B_Cu.gbl, neOSensorv5_panelized-B_Mask.gbs, neOSensorv5_panelized-B_SilkS.gbo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]
2021-02-12 tweaked neOSensor-lorawan arduino menu
2021-02-12 minor fix in arduino menu for lorawan neOSensor
2021-02-17 added TODO notes about PCB-v5
2021-03-31 added initial support to neOSensor PCB v5 :)
2021-03-31 start mods for pcb v5.1
    [neOSensorV5.kicad_pcb]
2021-03-31 update neOSensorV5 schematic
    [neOSensorV5.sch]
2021-04-02 updated pcb v5 layout
    [neOSensorV5.kicad_pcb]
2021-04-02 update PCB V5.1
    [neOSensorV5.kicad_pcb]
2021-04-02 new neOSensor V5.1 PCB done :)
    [BOM.ods, neOSensorV5.kicad_pcb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]
2021-04-04 prepare migration to esp32 1.0.6
2021-04-05 libs update, MQTT API for settings, move to esp32 1.0.6
2021-04-07 added sntp callback for ESP32
2021-04-13 added esp32 flag for NTP from DHCP server
2021-05-21 added preliminary support for our own kicad libs
2021-05-21 add lib in kicad-lib & add neOClock
    [7_segment_1.8p.igs, Alim.sch, digit.sch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]
2021-05-25 first neOClock pcb along with lorawan
2021-05-26 added original neOSensor-lorawan pcb ... then create lorawan-v2
    [neOSensor Cubecell_V1.kicad_pcb, neOSensor Cubecell_V1.sch]
2021-06-01 mise a jour des schema
    [neOClock.kicad_pcb, neOClock.sch, neOSensor Cubecell_V1.kicad_pcb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]
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2021-06-09 lorawanV2 schematic is ok. PCB is on way
    [neOsensor-LoRaWANV2.sch]
2021-06-09 lorawan-v2 pcb update
    [neOsensor-LoRaWANV2.kicad_pcb, neOsensor-LoRaWANV2.sch]
2021-06-10 neOSensor-LoRaWAN V2 ready for manfacturing
    [LoRaWANV2_panelized-B_Cu.gbl, LoRaWANV2_panelized-B_Mask.gbs, LoRaWANV2_panelized-B_SilkS.gbo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]
2021-06-14 maj schema + route
    [neOClock.kicad_pcb, neOClock.sch]
2021-06-24 added note for neOSensor pcb V5.2
    [neOSensorV5.sch]
2021-06-25 lorawanV2 docs update
    [BOM.ods, neOsensor-LoRaWANV2.csv, neOsensor-LoRaWANV2.sch]
2021-07-01 neOSensor LoRaWAN V2.1 pcb
    [neOsensor-LoRaWANV2.kicad_pcb]
2021-07-02 new LoRaWAN V2.1 sent to manufacturing
    [BOM.ods, LoRaWANV2-empty_panelized.kicad_pcb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]
2021-07-05 comment about esp32/GPIO15 being high at boot
    [neOSensorV5.sch]
2021-08-24 temperature module now send data upon modification, sharedJSON structure updated
2021-08-25 added data rounding to sensors and double i2c scan to improve detection
2021-08-26 added device status along with additional messages sent according to status change
2021-08-26 bug workaround for esp8266 targets about loadsensoconfig in digital and airquality modules ... investigations pending
    [neosensor.ino]
2021-08-27 corrected esp8266 stack issue due to ways too large StaticJsonDocument
    [neosensor.ino]
2021-09-05 improved oled display I2C detection
2021-10-21 corrected first time format SPIFFS now subsequently mounted FS
2021-10-25 sht2x hunt for bug ...
    [neosensor.ino]
2021-10-25 sht2x humidity bug hunt
    [neosensor.ino]
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2021-10-26 sht2x driver corrected
2021-10-26 airquality serial sensor is on way
2021-10-28 sample PMS5003 code update
2021-10-31 added PMS library along with test sample code
2021-10-31 pms_serial sensor is on way
2021-11-01 pms_serial driver is on way
2021-11-03 added support for multiple values,subIDs and sensorUnits to get sent back from a single sensor
2021-11-03 pm_serial driver is on way
2021-11-04 corrected TZ for esp32 with daylights savings now working
    [neosensor.ino]
2021-11-05 preliminary support for single airquality sensor sending back multiple values and subIDs
2021-11-10 serial driver for PMs still on way
2021-11-10 PMSx003 serial sensors integrated :)
2021-11-19 added IKEA pm sensor :)
2021-11-19 added SDS011 PM sensor
2021-11-22 added powerSave option ==> disabling power save mode for SDS011 (noisy sensor)
2021-12-02 added DXF files for laser cutter
    [neOSensor_IR.dxf, neOSensor_V2.1_back.dxf, neOSensor_V2.2_back.dxf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]
2021-12-03 added new LoRa-E5 from seeed and added new lasercut files
2021-12-09 corrected neOSensorV5 desktop case
    [neOSensor_bureau.dxf]
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2022-02-25 mod IKEA PM sensor with new command
2022-03-07 on way to Sensirion SDC4x i2c CO2+temp+hygro sensor
2022-03-13 SCD4x sensor is on way ...
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2022-03-15 trying to overcome i2c comm issues with TSL2561
2022-03-15 corrected TSL2561 detection with latest i2c primitives from neOCampus
    [ikea_pm2.5.ino]
2022-03-16 corrected multi-sensors corner case in general calls
2022-03-16 SCD4x integration is over --> sensor operational :)
2022-03-18 switch back to regular IKEA PMsensor commands + added hex_dump for frames
2022-04-18 added SoftwareSerial port2 for esp8266 serial sensors. Tests required!
2022-08-08 updated boards definitions along with lwipV2 recompiled with DHCP support for NTP servers
2022-08-15 corrected boards definition for esp32
2022-08-17 corrected display of currently used NTP server(s)
    [neosensor.ino]
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2022-09-23 added ESP32 AES hardware encyption and decrypt example
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2023-10-03 lasercut on way to update
    [neOSensor_bureauV2_Top3mm.dxf, tmp_neOSensor_bureauV2_Top3mm.dxf]

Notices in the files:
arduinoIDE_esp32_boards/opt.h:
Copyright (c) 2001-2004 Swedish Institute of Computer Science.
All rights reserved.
